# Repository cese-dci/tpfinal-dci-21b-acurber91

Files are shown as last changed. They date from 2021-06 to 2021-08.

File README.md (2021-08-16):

## Trabajo Práctico Final de la asignatura DCI ##

Este repositorio contiene el Trabajo Práctico Final de la asignatura de Diseño de Circuitos Impresos de la carrera Maestría en Internet de las Cosas (MIoT) de la FIUBA.

* **Autor**: Agustín Curcio Berardi
* **Revisor**: Gustavo Zocco
* **Docente**: Diego Brengui
* **Título del Trabajo**:  Adafruit Feather M0 with LoRa Radio Module Adaptation
* **Descripción**:  Plataforma modular Feather desarrollada por Adafruit con el mismo concepto de las placas Arduino. Existen diversas placas con un mismo formato físico y diferente hardware montado. Esta versión en particular incorpora un microcontrolador ARM Cortex-M0 junto con un módulo LoRa basado en el chipset SX1276 de la empresa Semtech.

<p align="center">
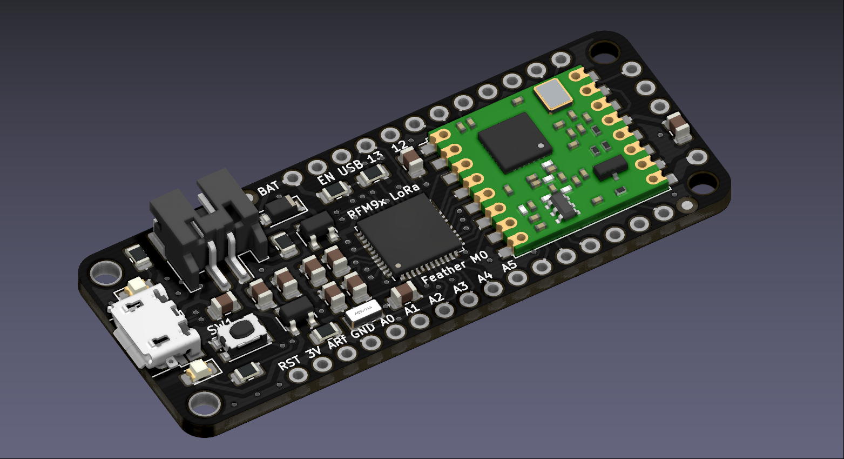
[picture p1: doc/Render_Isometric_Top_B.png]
    <br>
    <b>Figura 1</b>. Vista isométrica superior de la adaptación realizada. 
</p>

<p align="center">
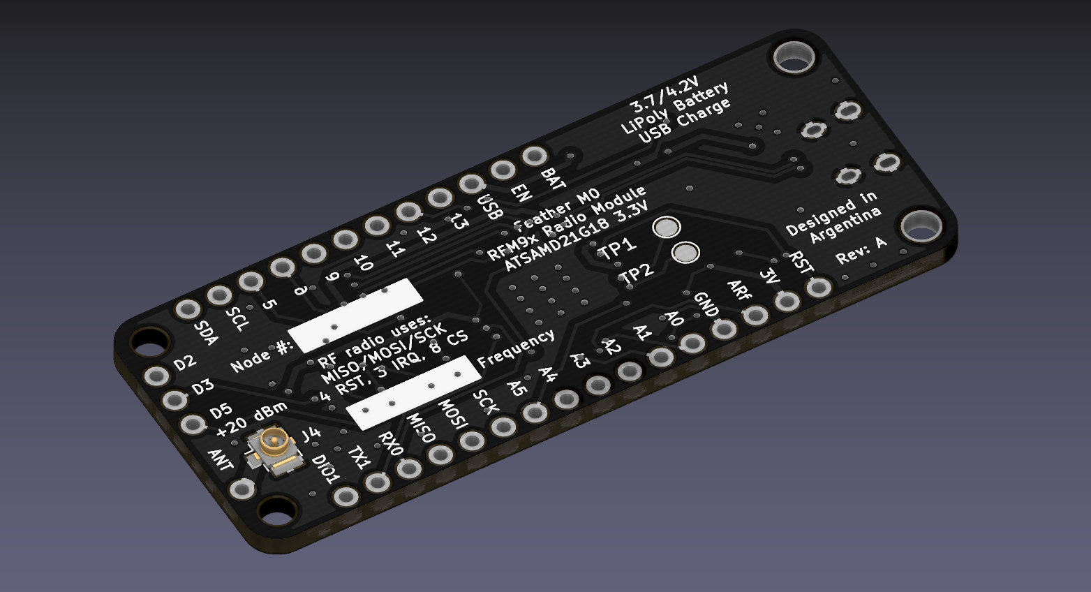
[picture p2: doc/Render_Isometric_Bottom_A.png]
    <br>
    <b>Figura 2</b>. Vista isométrica inferior de la adaptación realizada. 
</p>

<p align="center">
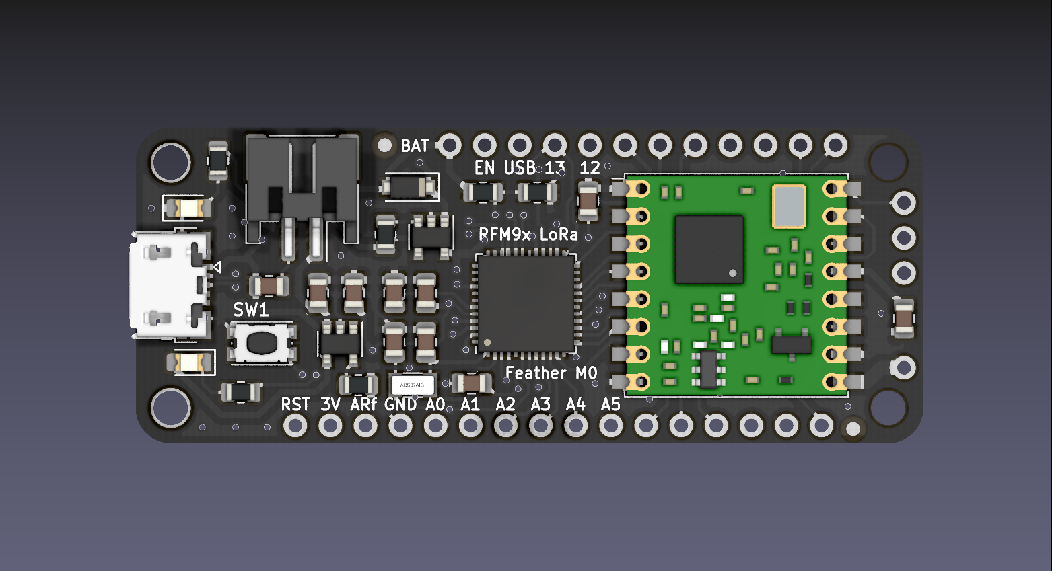
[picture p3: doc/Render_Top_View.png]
    <br>
    <b>Figura 3</b>. Vista superior de la adaptación realizada. 
</p>

<p align="center">
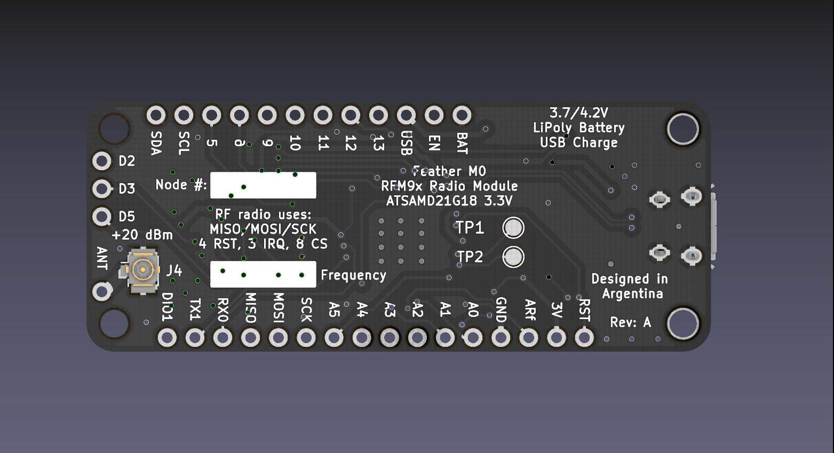
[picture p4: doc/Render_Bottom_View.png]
    <br>
    <b>Figura 4</b>. Vista inferior de la adaptación realizada. 
</p>

## Detalles de la adaptación ##

Este Trabajo Práctico realizó una adaptación de la placa utilizada como propuesta para poder cumplir con los requerimientos establecidos en la materia. Así:

- Se modificaron los tamaños de los componentes pasivos. Se pasó de tamaño 0603 a 0805.
- El cambio de tamaño de los componentes pasivos requirió modificar las dimensiones del circuito impreso. La altura no se modificó para garantizar la compatibilidad con otras placas de la línea Feather. No obstante, sí se modificó el largo total de la misma para hacer lugar a componentes de mayor tamaño. El circuito impreso final es 6,223 mm más largo que el original.
- Se agregó un segundo fiducial que no estaba presente en el diseño original.
- Se adoptó HASL como terminación superficial en lugar de ENIG.

## Licencia de este trabajo ##
Designed by Limor Fried/Ladyada for Adafruit Industries. Creative Commons Attribution/Share-Alike. See License.txt for additional information.

## Estructura ##

El Trabajo Práctico Final tiene la siguiente estructura:

* doc: Toda la información sobre el circuito, principalmente de autoría o procesamiento propio.
  * Notas con cálculos.
  * Fotos de los prototipos.
* info: Toda la información recolectada, principalmente de terceros, como por ejemplo:
  * Hojas de datos.
  * Notas de aplicación.
  * Información de productos comerciales.
* pcb: Archivos de diseño esquemático y PCB.
  * Archivo esquemático en PDF.

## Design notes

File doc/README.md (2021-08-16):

## Cálculos ##

Si bien no se encontraba dentro del alcance del Trabajo Práctico calcular líneas de impedancia controlada, se efectuaron dichos cálculos utilizando la calculadora de KiCad y los resultados obtenidos fueron aplicados en el circuito impreso. Se requirió calcular una línea diferencial para la conexión USB y una línea de transmisión para la conexión de antena. Los resultados de dichos cálculos se muestran en las Figuras 1 y 2.

<p align="center">
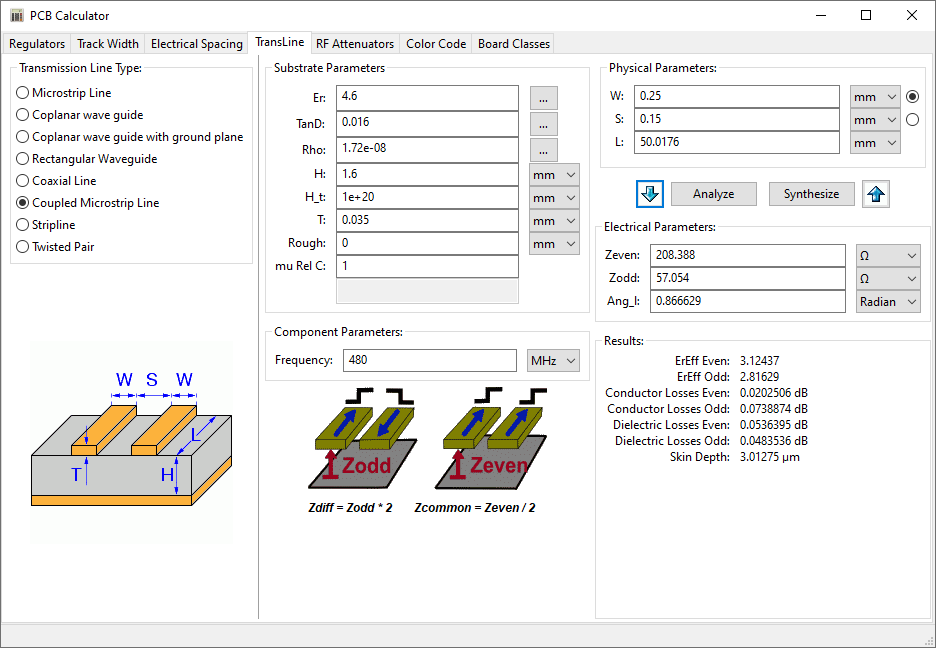
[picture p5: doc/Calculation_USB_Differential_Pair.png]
    <br>
    <b>Figura 1</b>. Cálculo de línea diferencial USB. 
</p>

<p align="center">
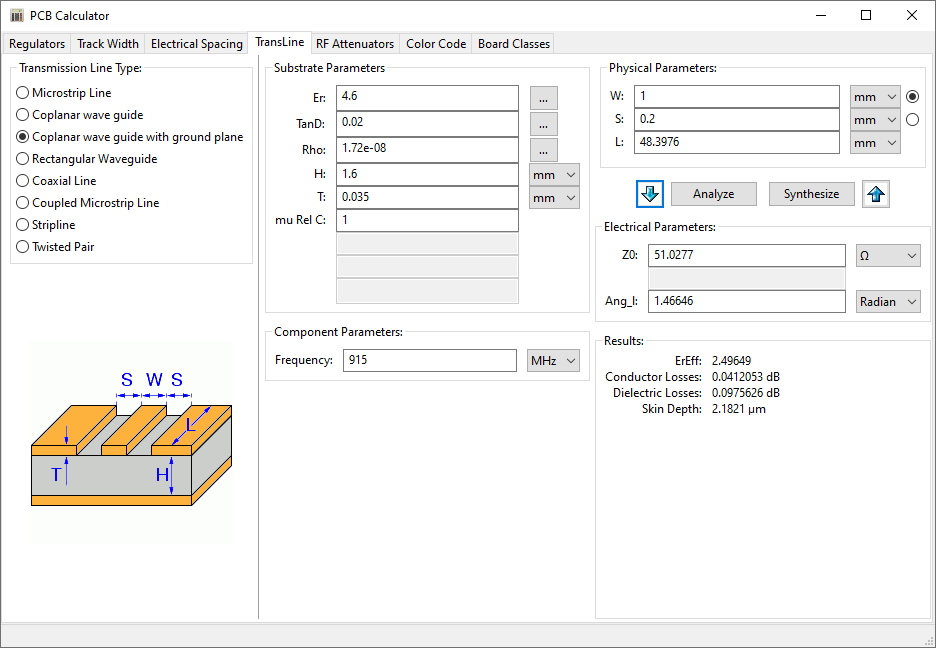
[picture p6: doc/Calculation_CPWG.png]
    <br>
    <b>Figura 2</b>. Cálculo de la línea de transmisión. 
</p>

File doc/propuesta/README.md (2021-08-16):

## Propuesta ##

Se propuso realizar una adaptación de la placa Adafruit Feather M0 Radio with LoRa Radio Module.

> <b>NOTA:</b> Más información sobre el trabajo se puede encontrar en las páginas web donde [se encuentra a la venta](https://www.adafruit.com/product/3178) junto con [los datos detallada de la misma](https://learn.adafruit.com/adafruit-feather-m0-radio-with-lora-radio-module/downloads).

<p align="center">
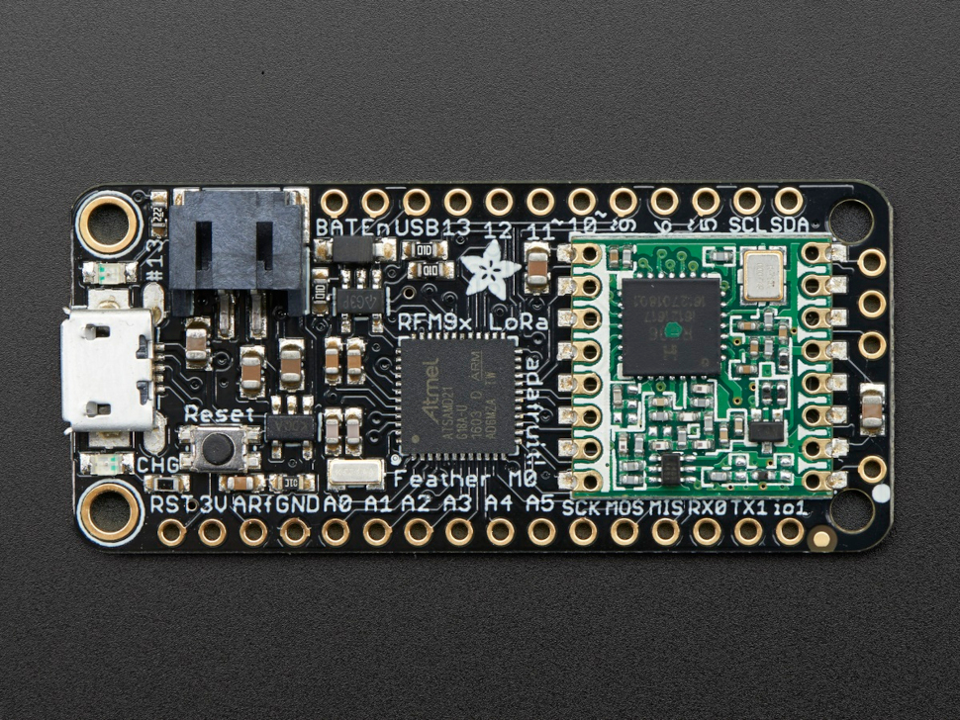
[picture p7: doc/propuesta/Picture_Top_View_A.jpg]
    <br>
    <b>Figura 1</b>. Vista superior de la placa. 
</p>

<p align="center">
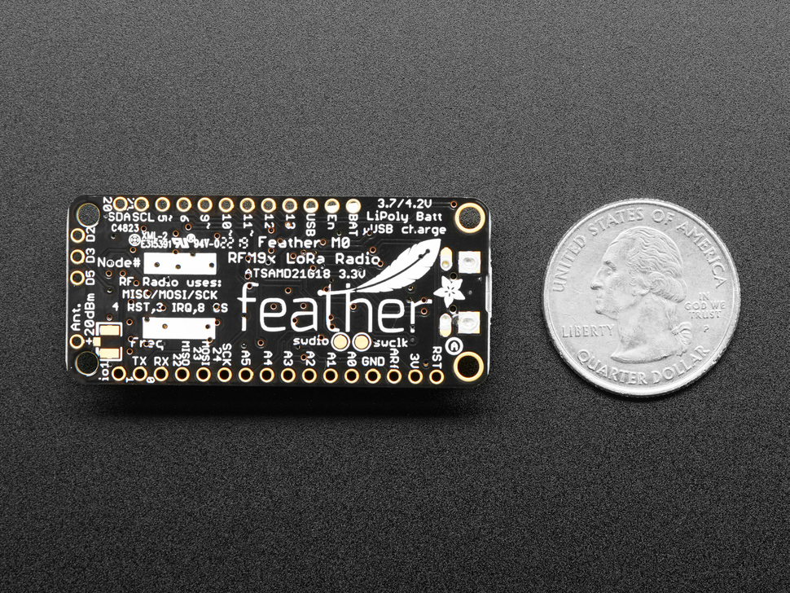
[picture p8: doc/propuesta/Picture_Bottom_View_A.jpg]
    <br>
    <b>Figura 2</b>. Vista inferior de la placa. 
</p>

<p align="center">
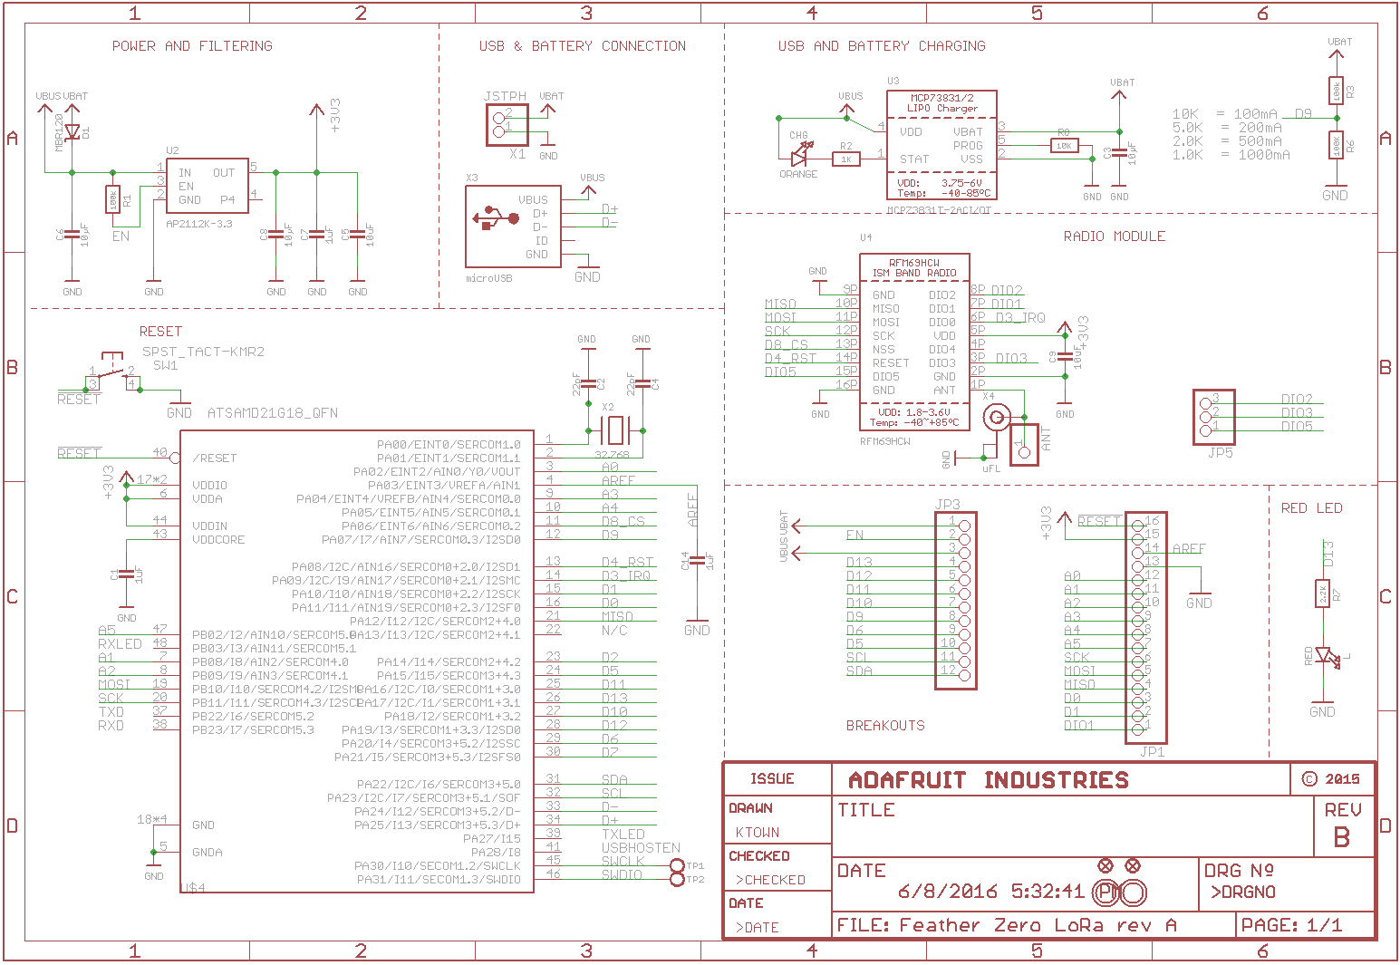
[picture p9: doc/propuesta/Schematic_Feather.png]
    <br>
    <b>Figura 3</b>. Diagrama esquemático. 
</p>

<p align="center">
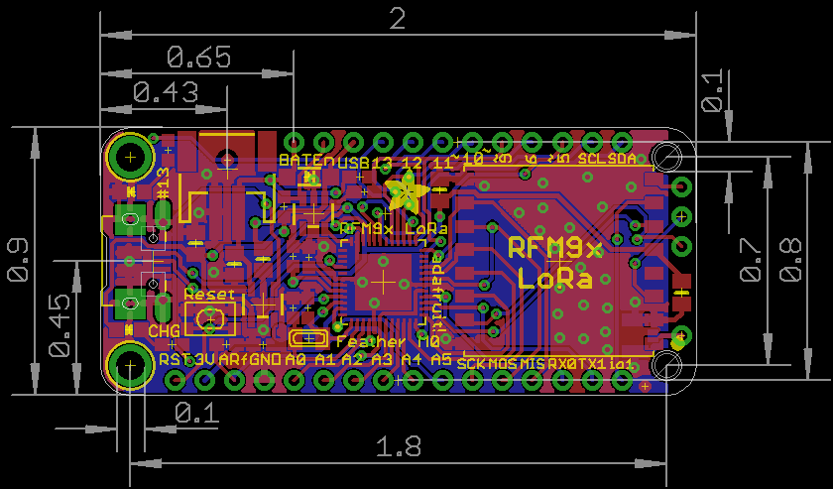
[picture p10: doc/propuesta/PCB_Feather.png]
    <br>
    <b>Figura 4</b>. Circuito impreso. 
</p>

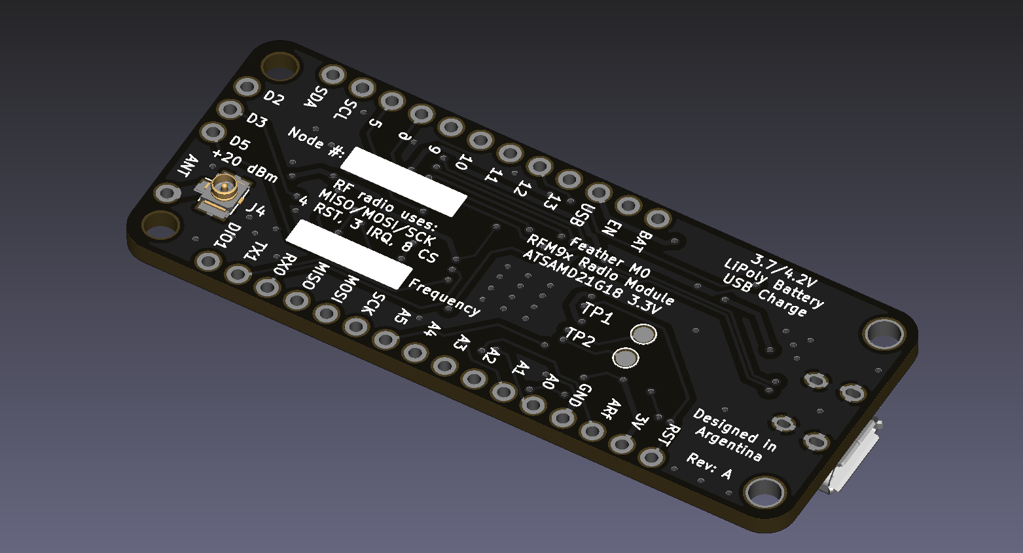
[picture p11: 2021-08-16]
doc/Render_Isometric_Bottom_B.png

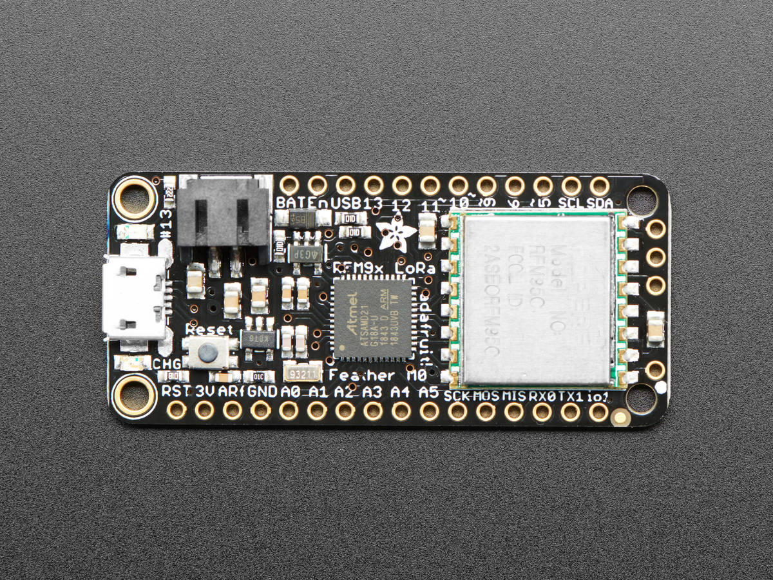
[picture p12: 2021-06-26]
doc/propuesta/Picture_Top_View_B.jpg

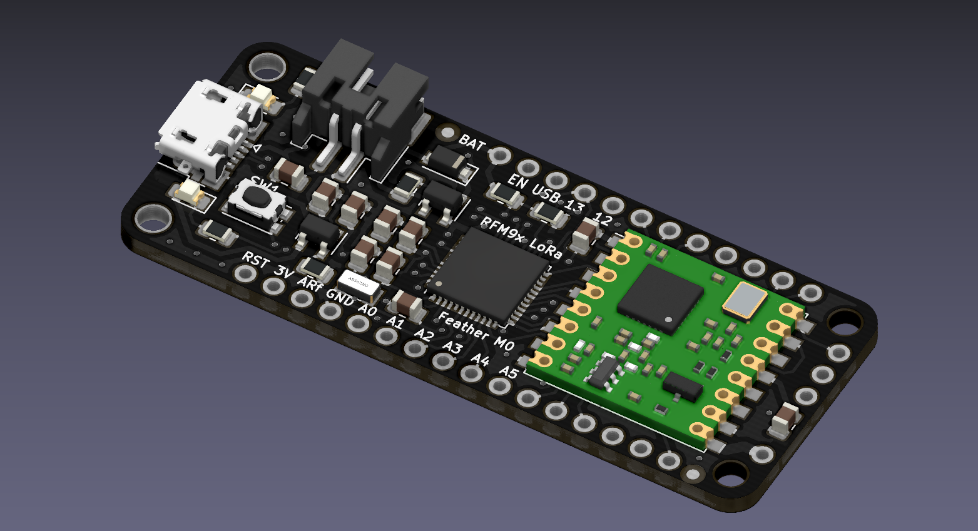
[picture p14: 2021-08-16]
doc/Render_Isometric_Top_A.png

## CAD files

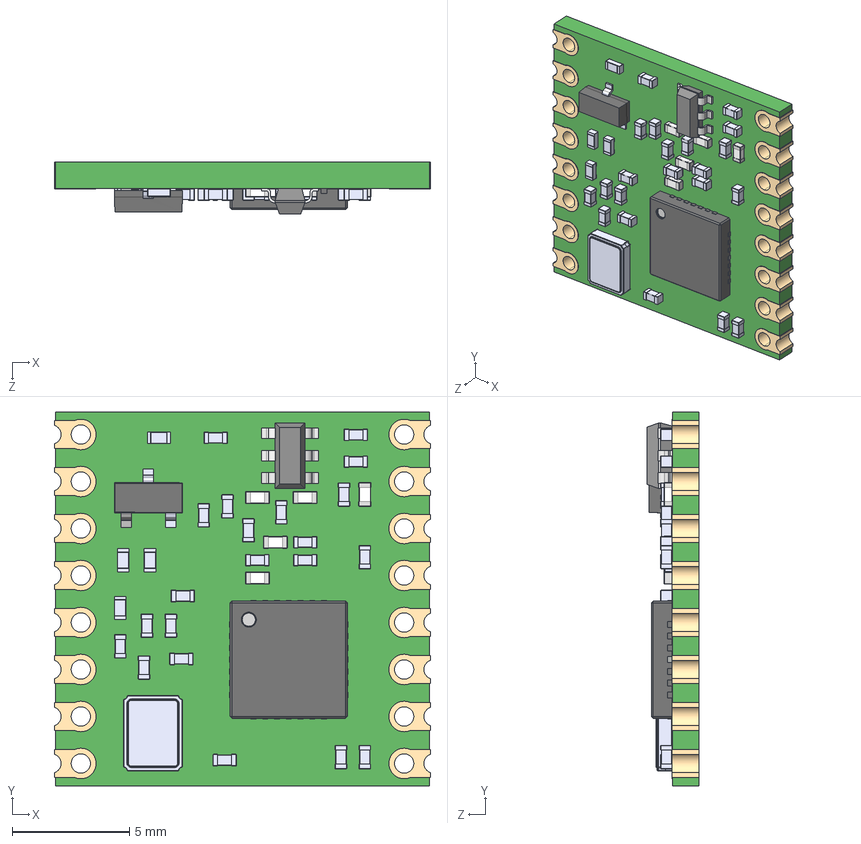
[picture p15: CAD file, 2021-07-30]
pcb/3d_models/Hoperf_RFM_95_96_97_98_1.step
16.0 x 15.9 x 2.23 mm
Board
Cap0402 x 21
SW3dPS-inductor_0402_white x 5
SW3dPS-SOT-23-6
QFN28
TXC_7M
Res0402 x 4
User_Library-3-lead_sot23-3
Goldcontact x 16

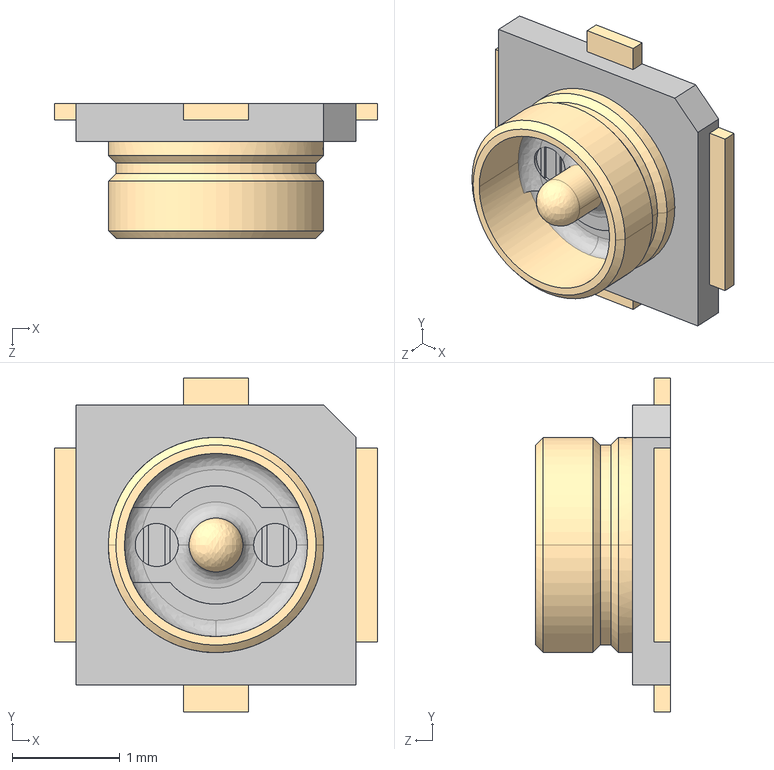
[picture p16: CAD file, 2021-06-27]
pcb/3d_models/Hirose_U.FL.step
3.00 x 3.10 x 1.25 mm

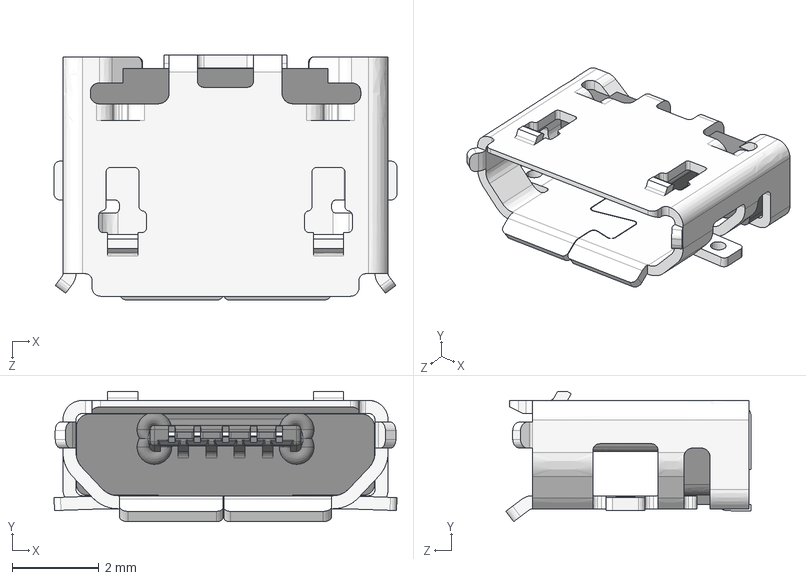
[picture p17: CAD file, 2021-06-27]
pcb/3d_models/Amphenol_10118192C.step
7.91 x 3.01 x 5.66 mm

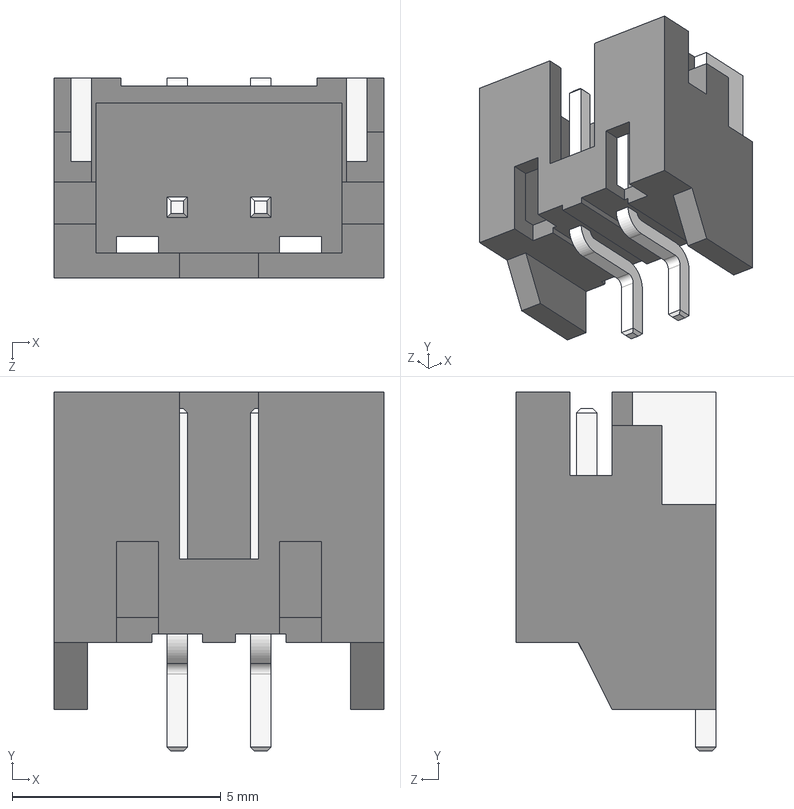
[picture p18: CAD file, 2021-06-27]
pcb/3d_models/JST_Connector.step
7.90 x 8.60 x 4.80 mm

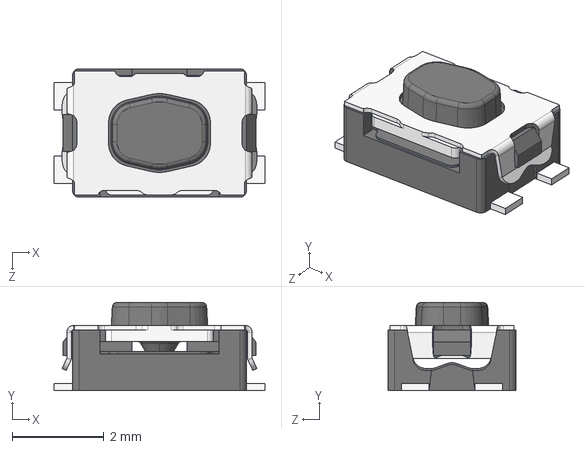
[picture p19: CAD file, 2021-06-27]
pcb/3d_models/C&K_KMR2_Switch.step
4.60 x 1.92 x 2.80 mm

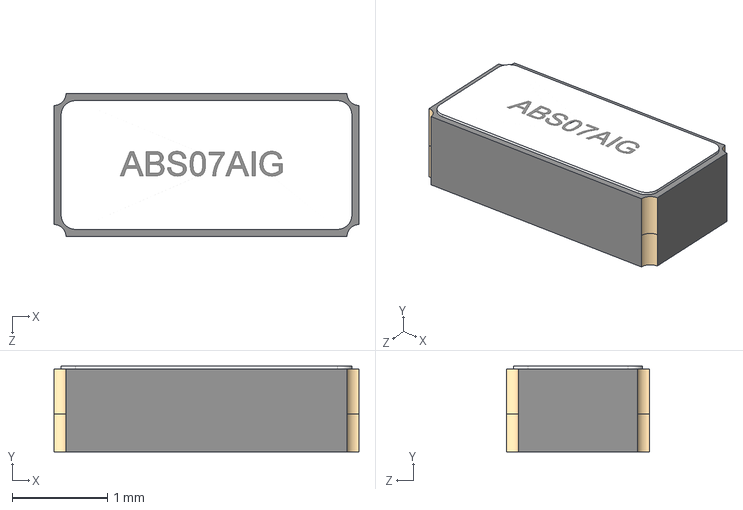
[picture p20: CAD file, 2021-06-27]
pcb/3d_models/Abracon_ABS07AIG.step
3.20 x 0.901 x 1.50 mm

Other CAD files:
pcb/3d_models/Hoperf_RFM_95_96_97_98.step

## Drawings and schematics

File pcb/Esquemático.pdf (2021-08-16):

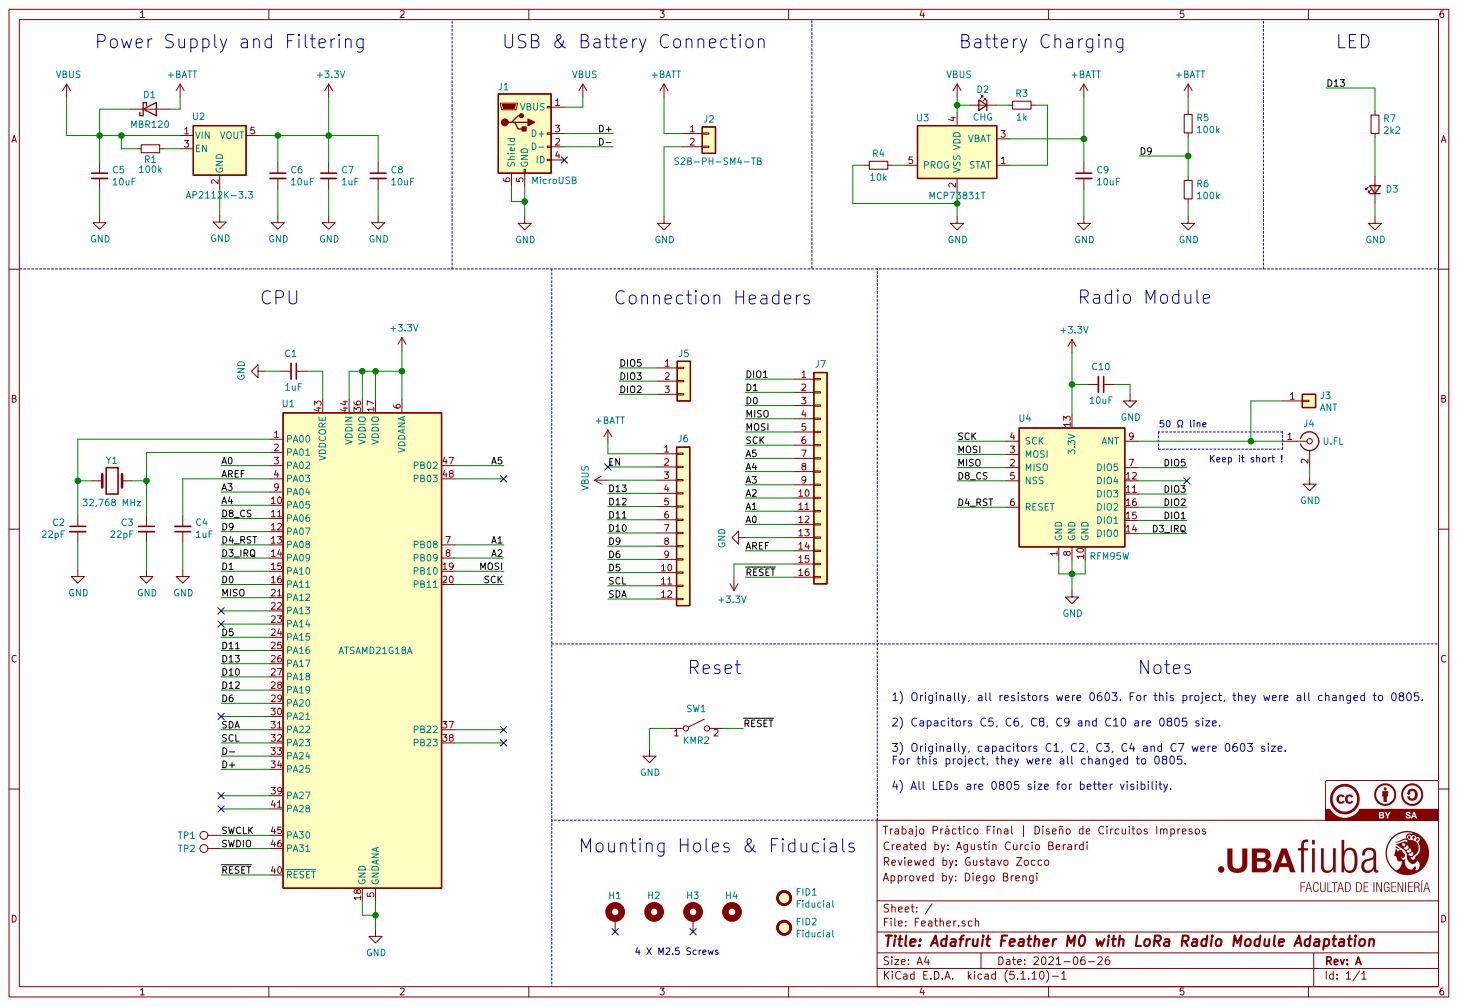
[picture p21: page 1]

Power Supply and Filtering

1 GND 10 DIO3 11 DIO4 12 3.3V 13 DIO0 14 DIO1 15 DIO2 16 MISO 2 MOSI 3 SCK 4 NSS 5 RESET 6 DIO5 7 GND

1) Originally, all resistors were 0603. For this project, they were all changed to 0805.

2) Capacitors C5, C6, C8, C9 and C10 are 0805 size.

3) Originally, capacitors C1, C2, C3, C4 and C7 were 0603 size.
For this project, they were all changed to 0805.

4) All LEDs are 0805 size for better visibility.

Created by: Agustín Curcio Berardi
Reviewed by: Gustavo Zocco
File: Feather.sch Sheet: / Approved by: Diego Brengi

Id: 1/1 Title: Adafruit Feather M0 with LoRa Radio Module Adaptation

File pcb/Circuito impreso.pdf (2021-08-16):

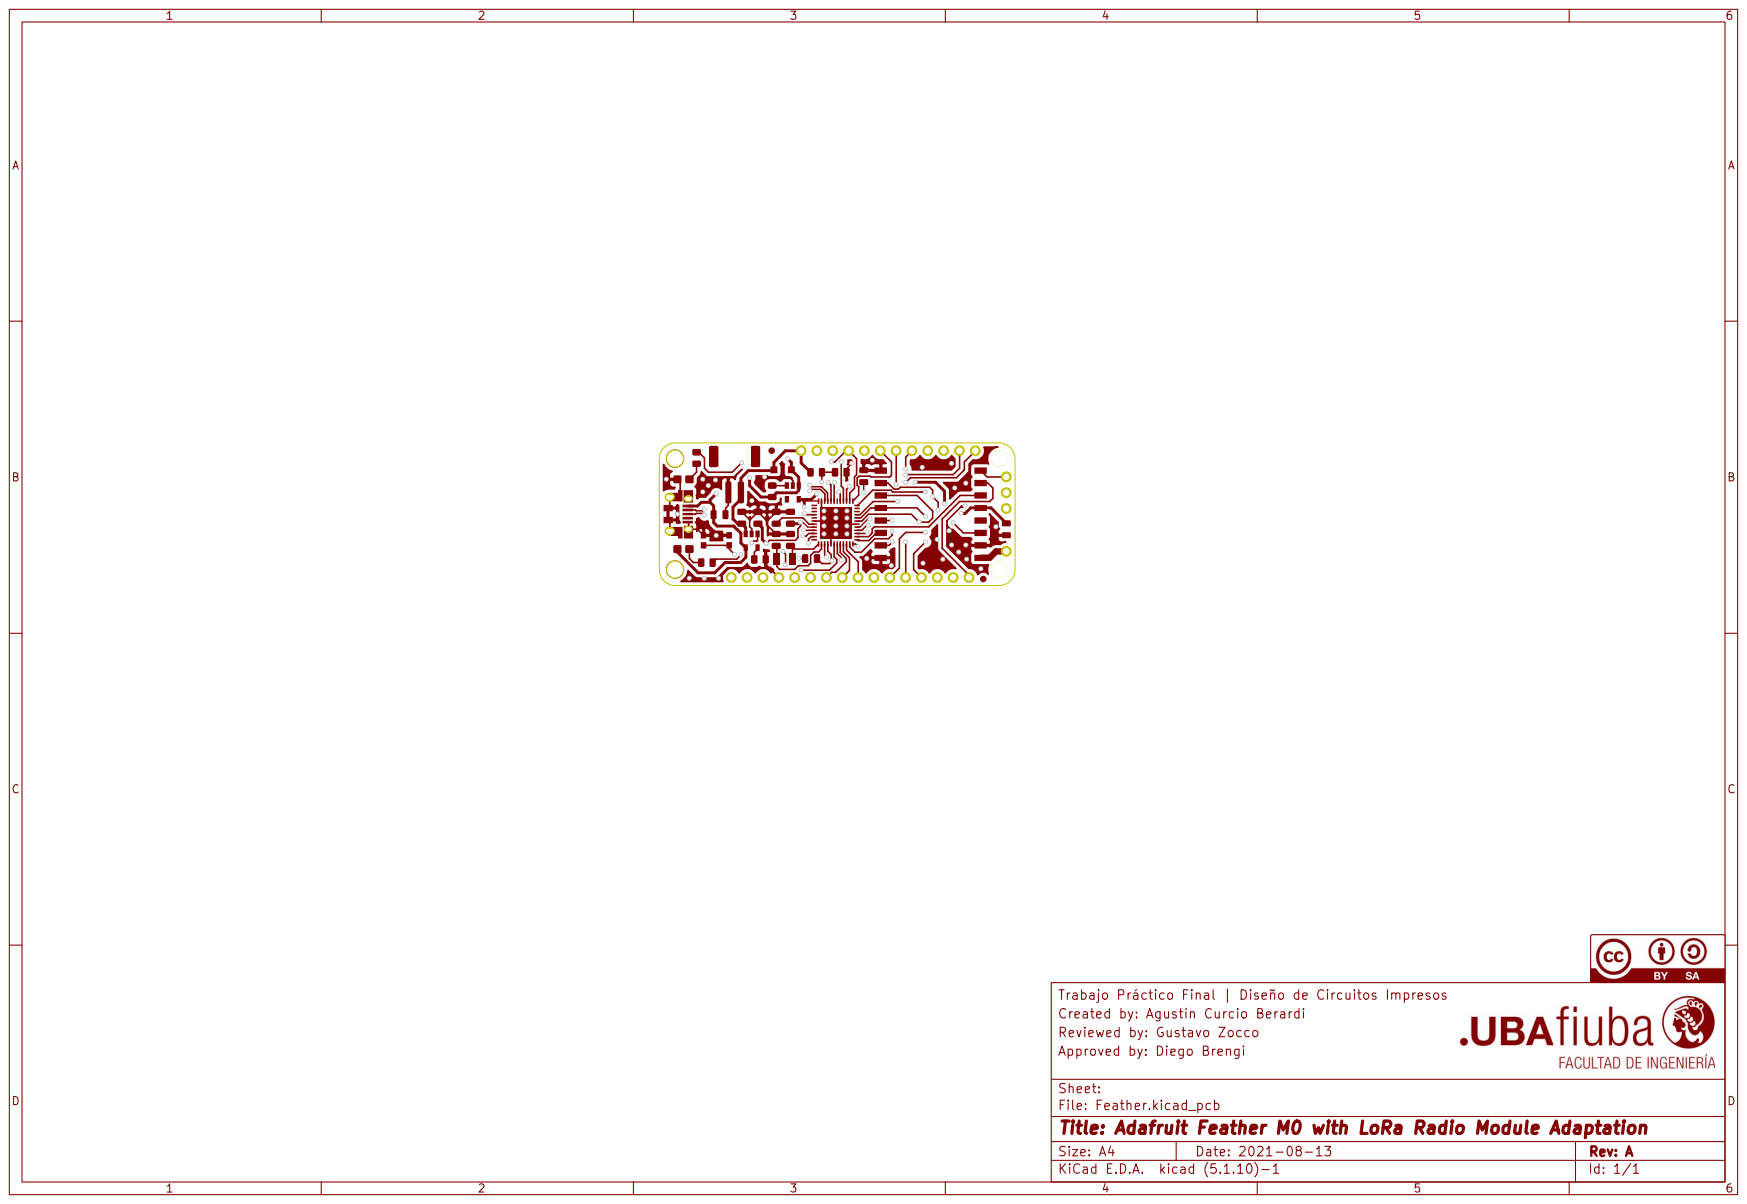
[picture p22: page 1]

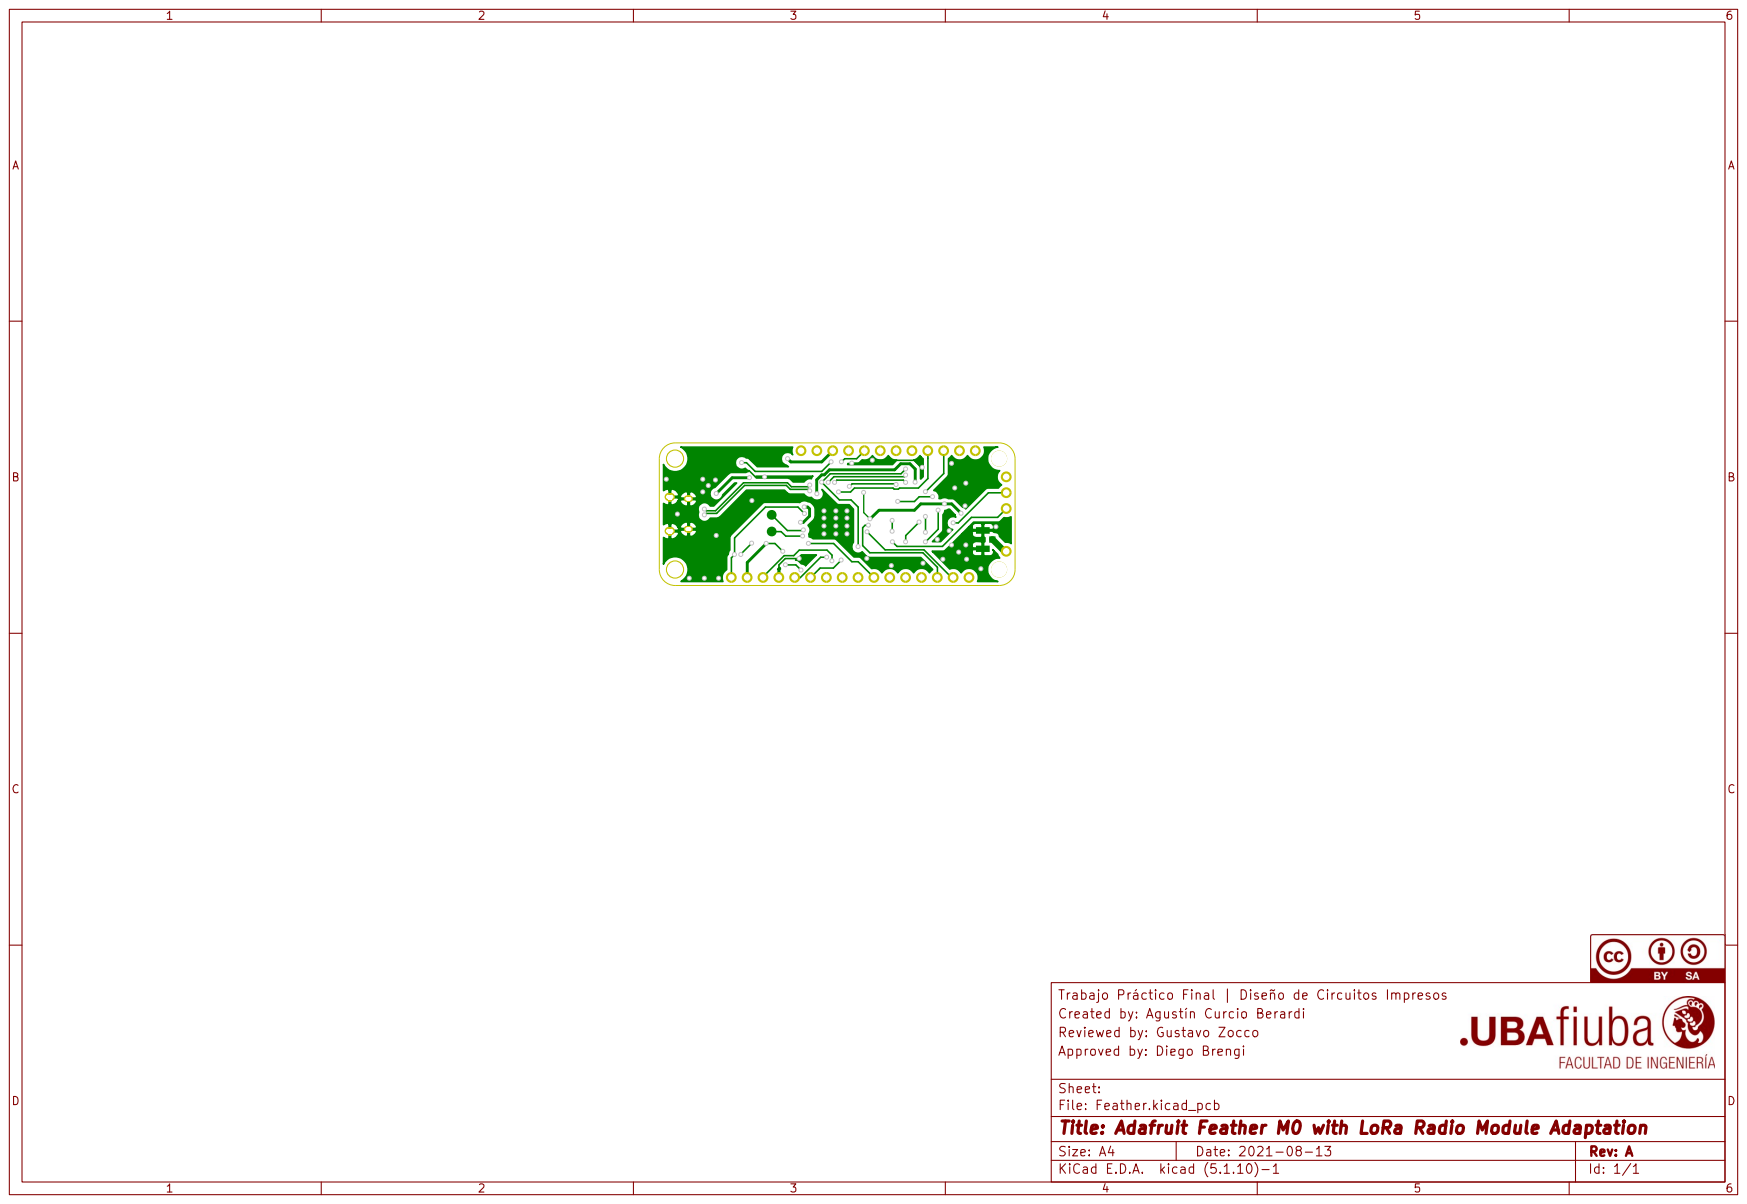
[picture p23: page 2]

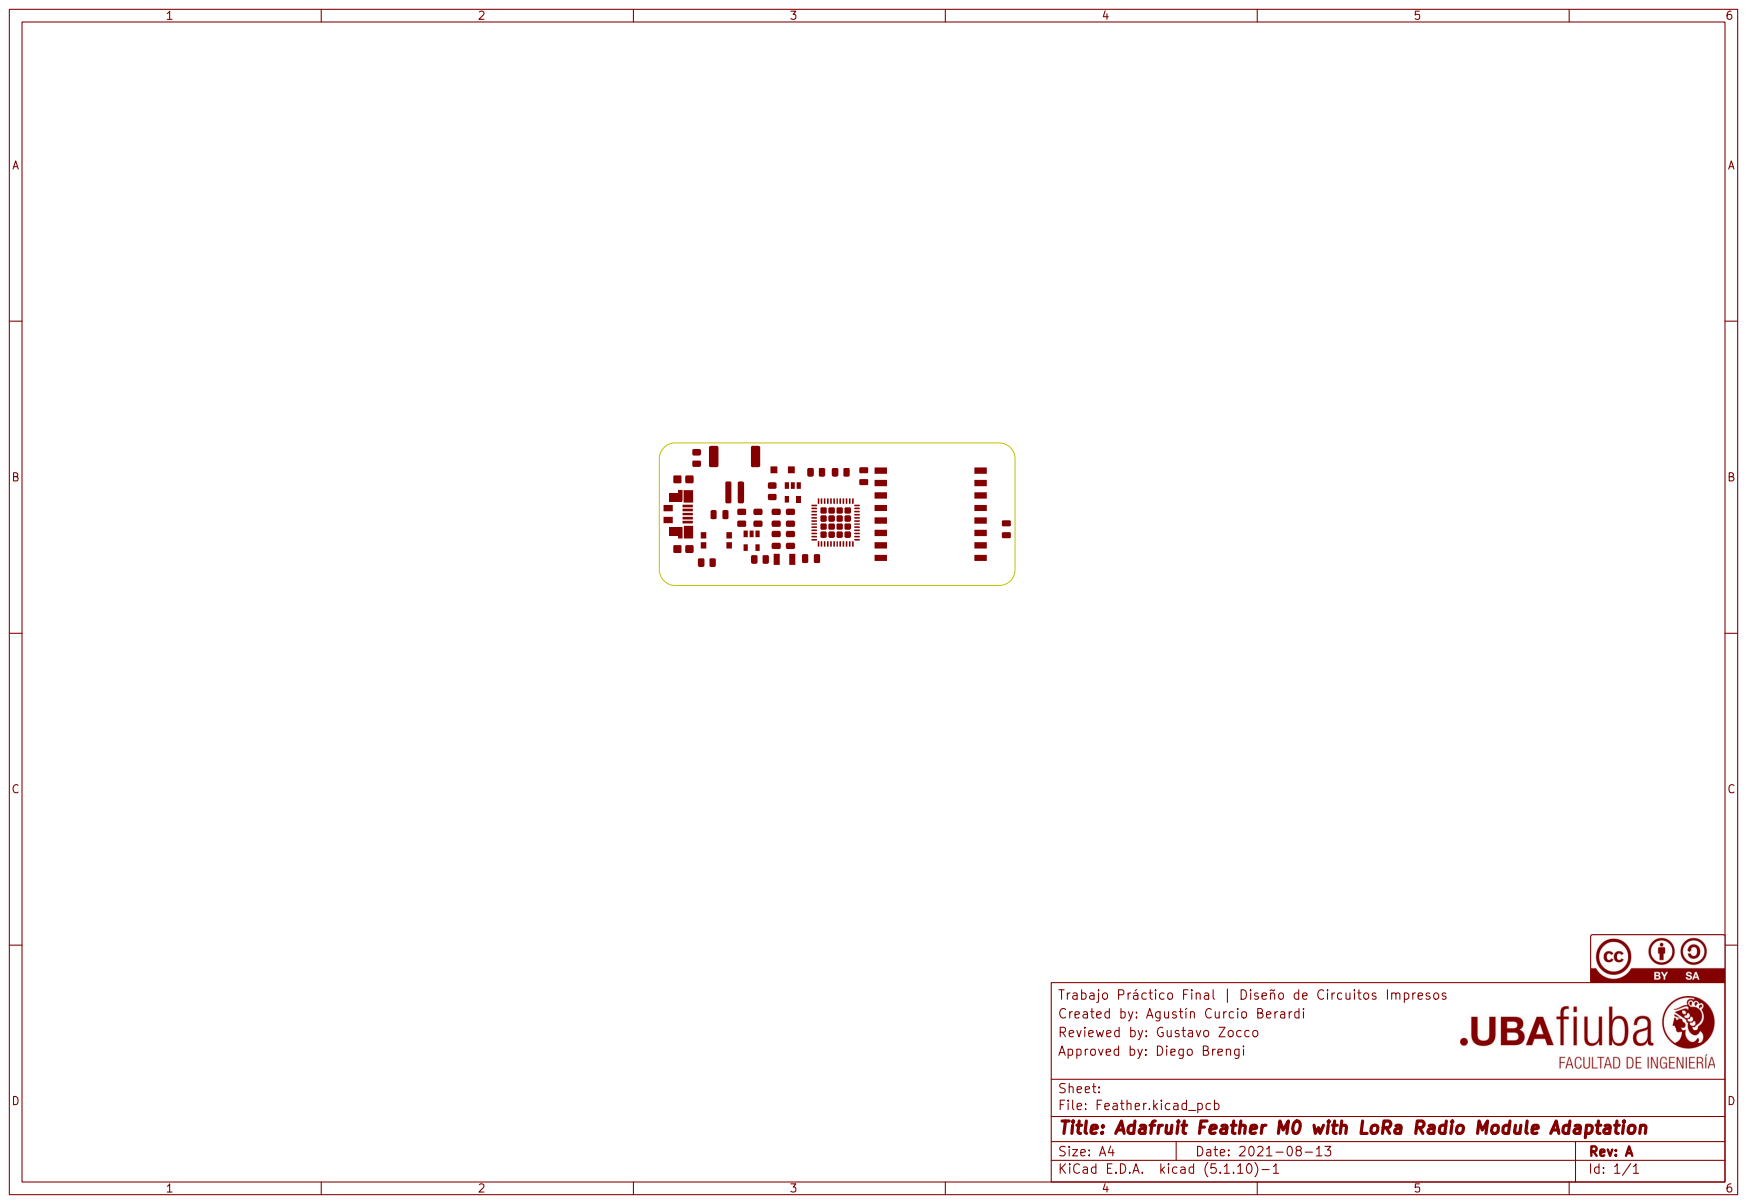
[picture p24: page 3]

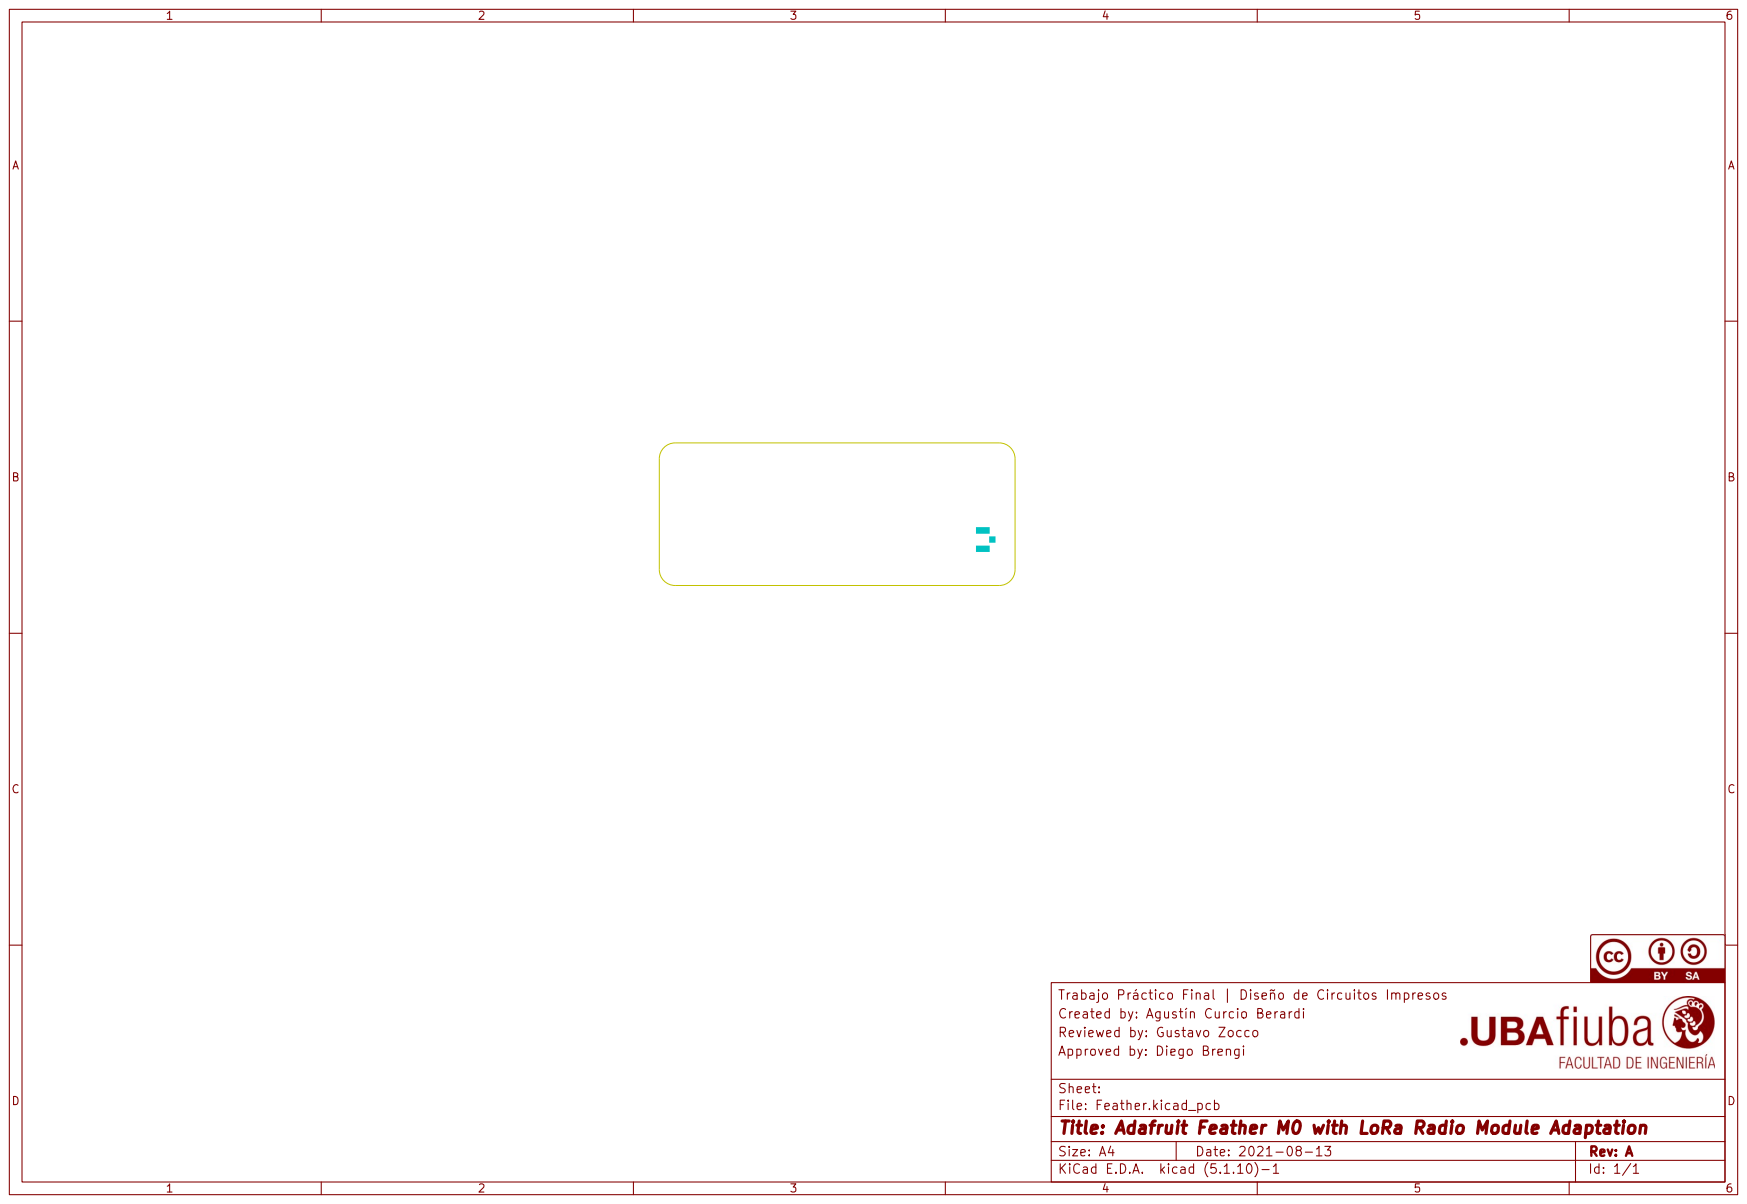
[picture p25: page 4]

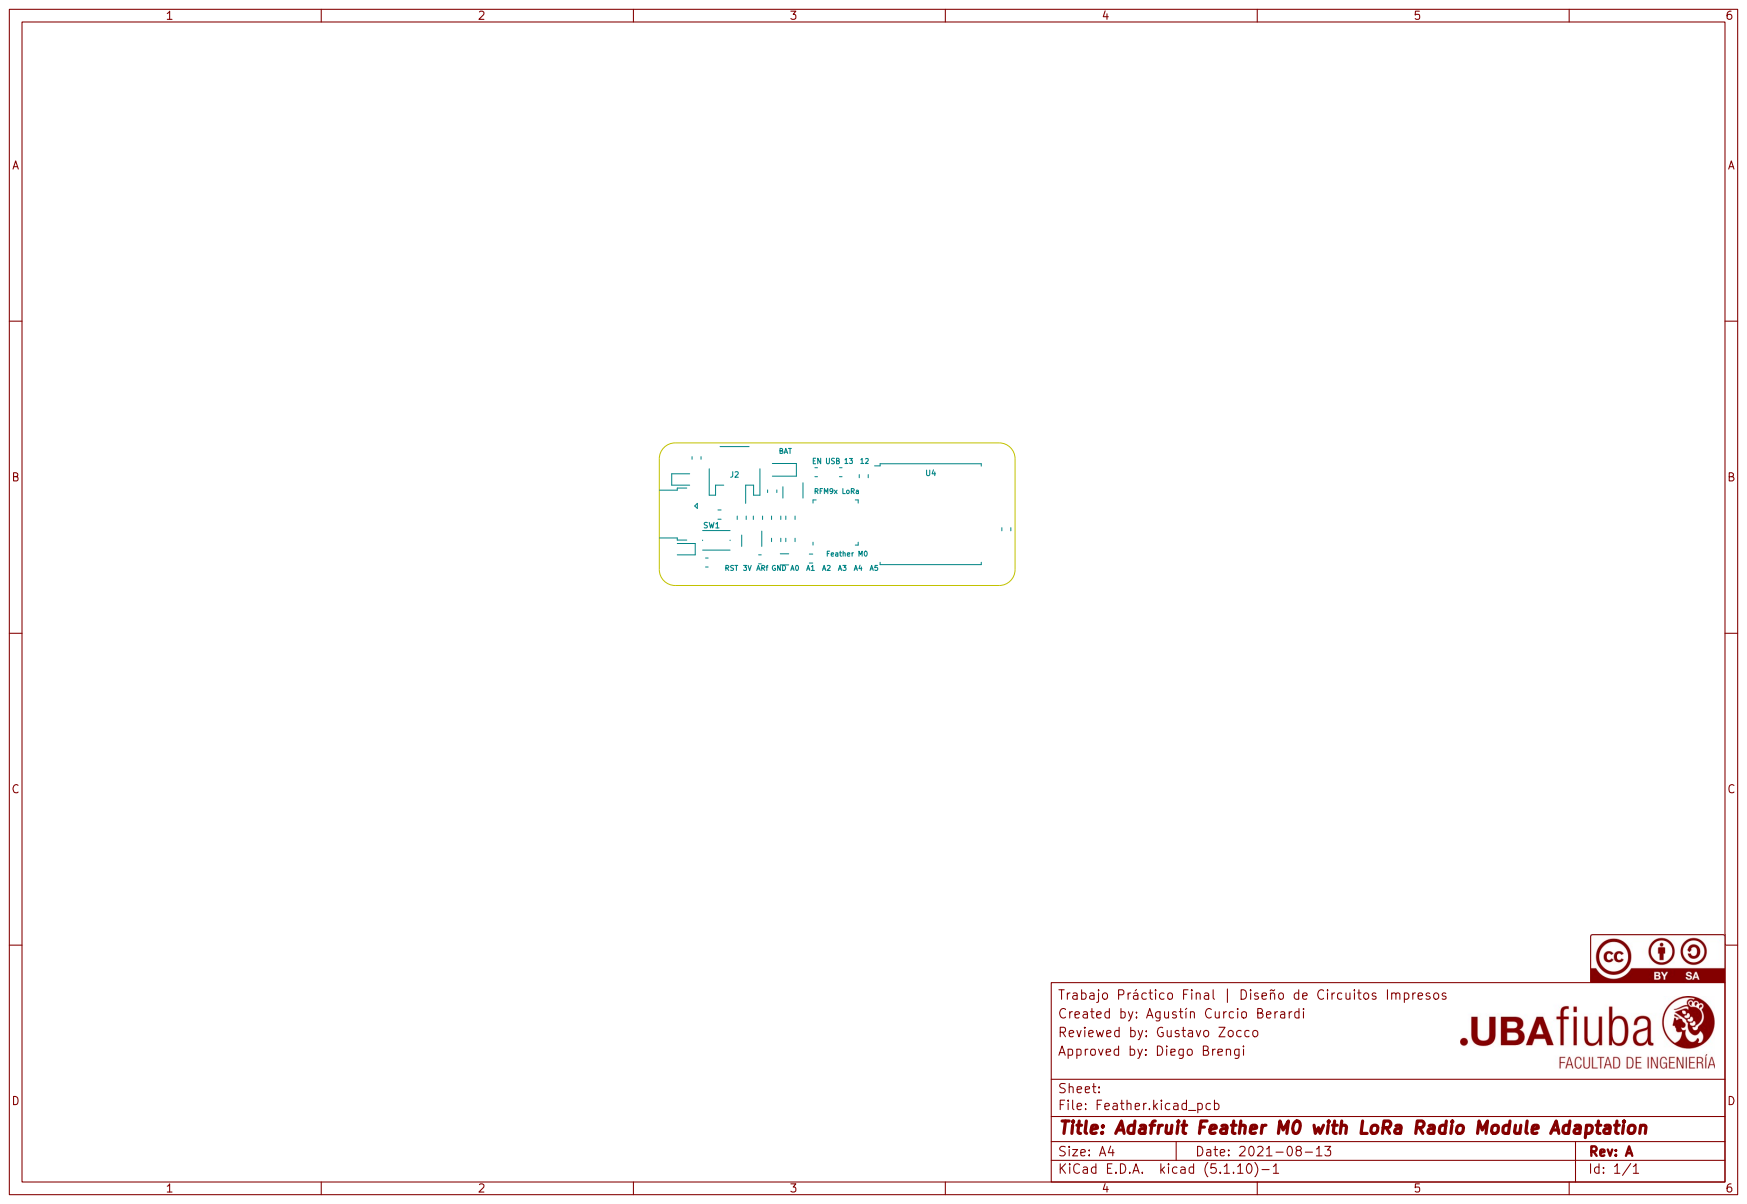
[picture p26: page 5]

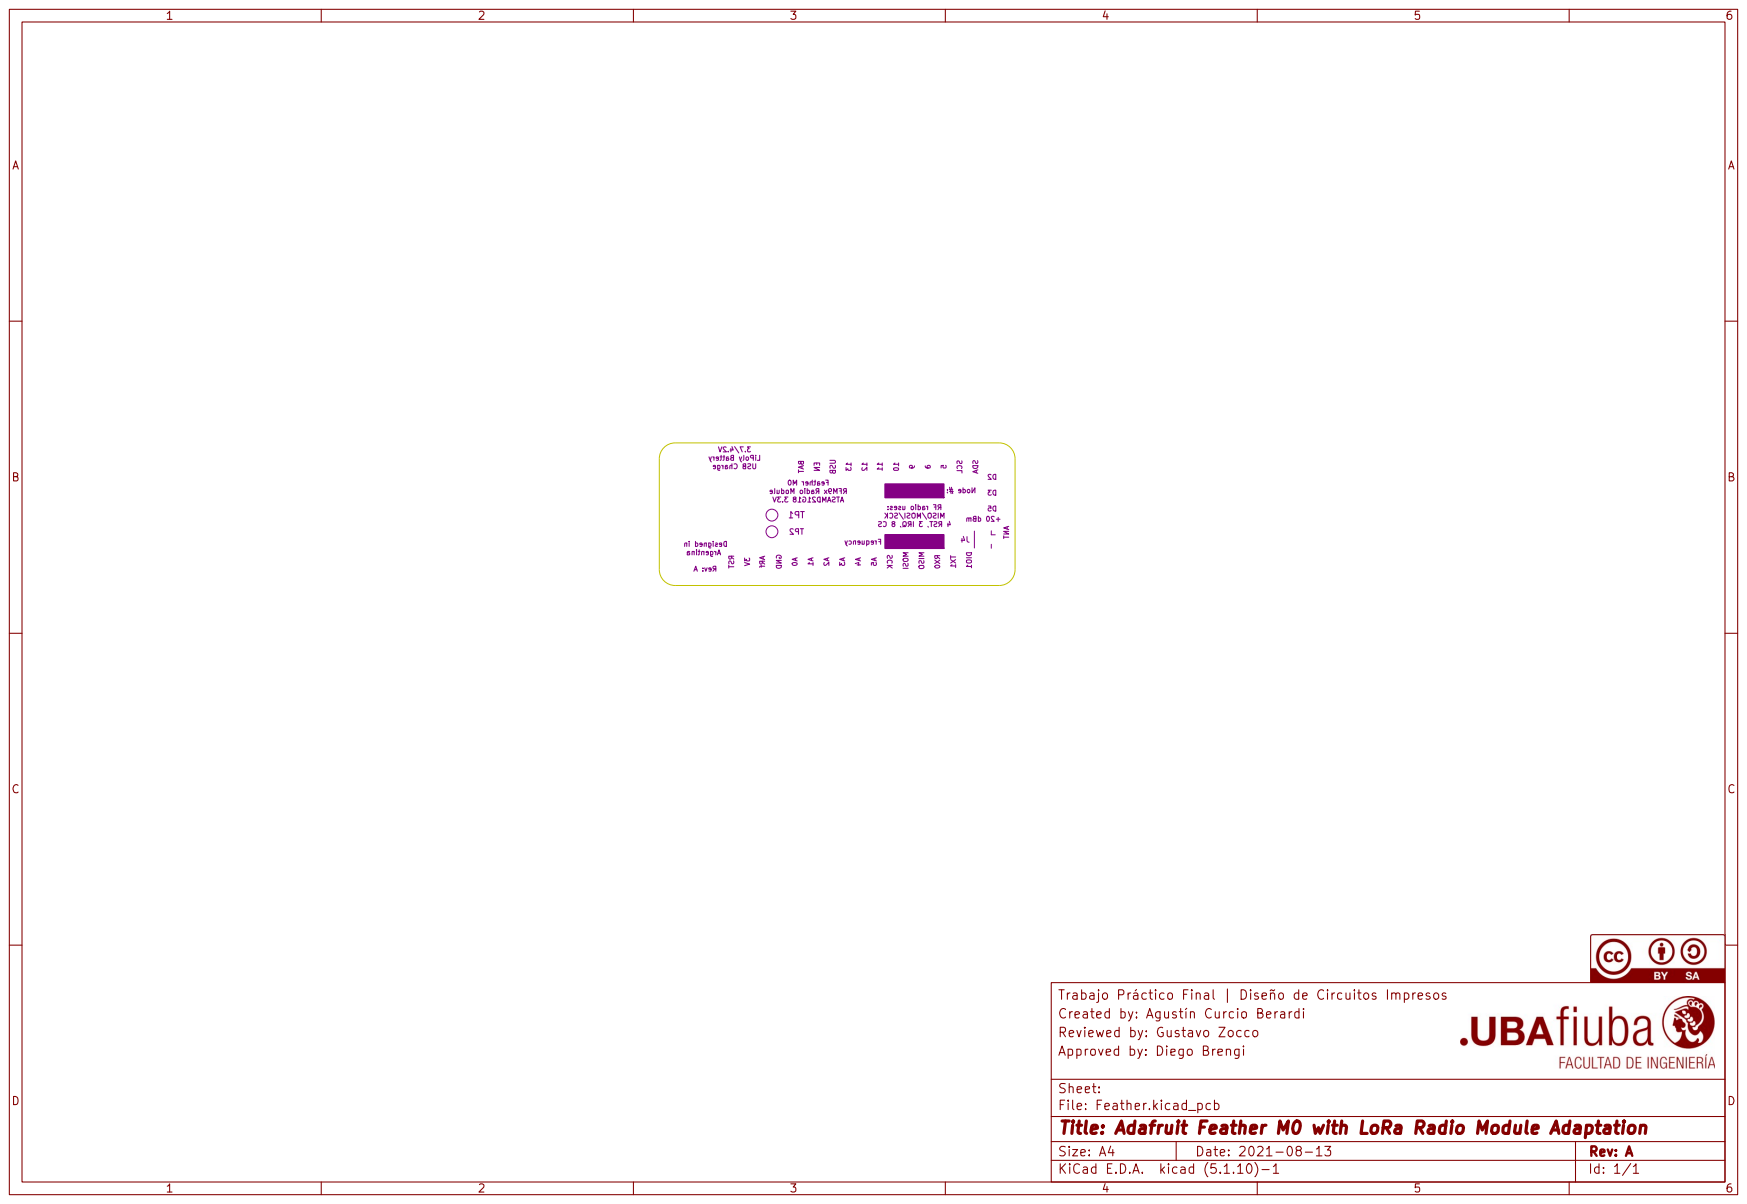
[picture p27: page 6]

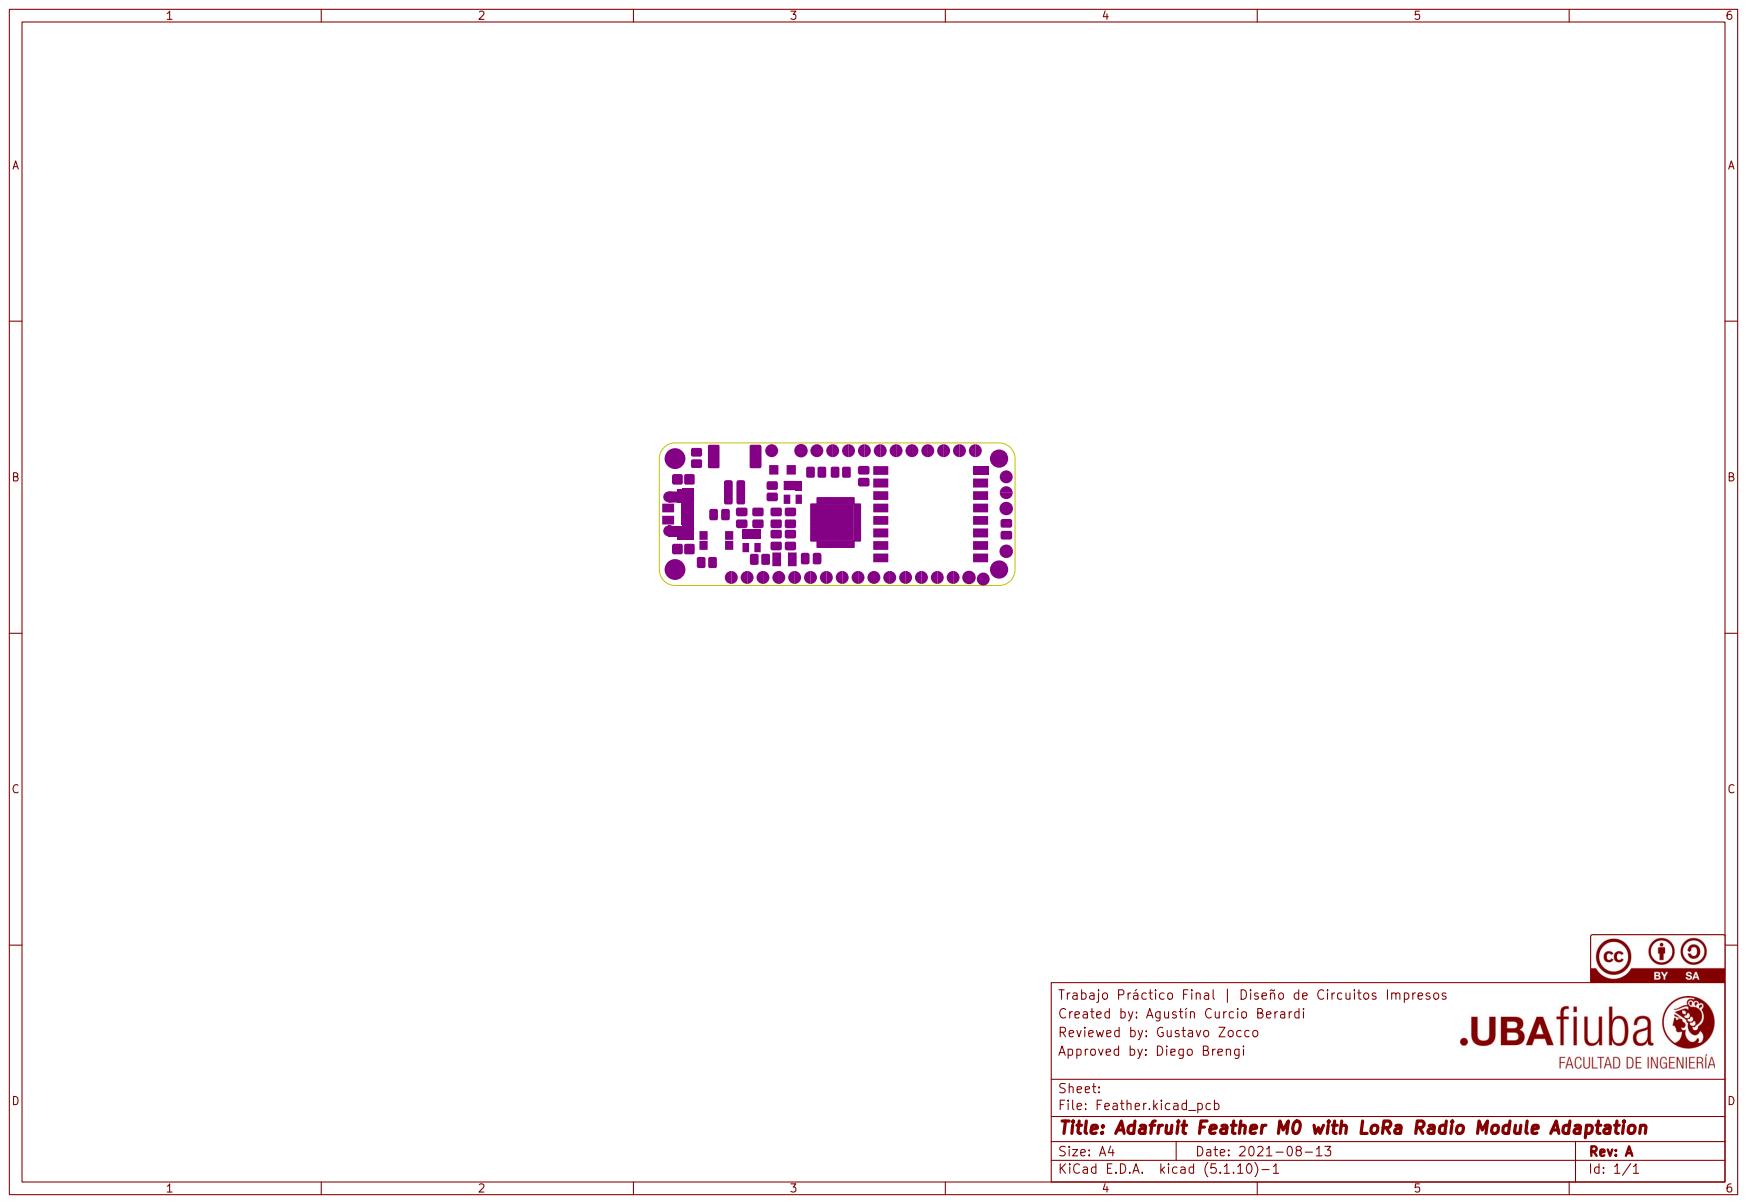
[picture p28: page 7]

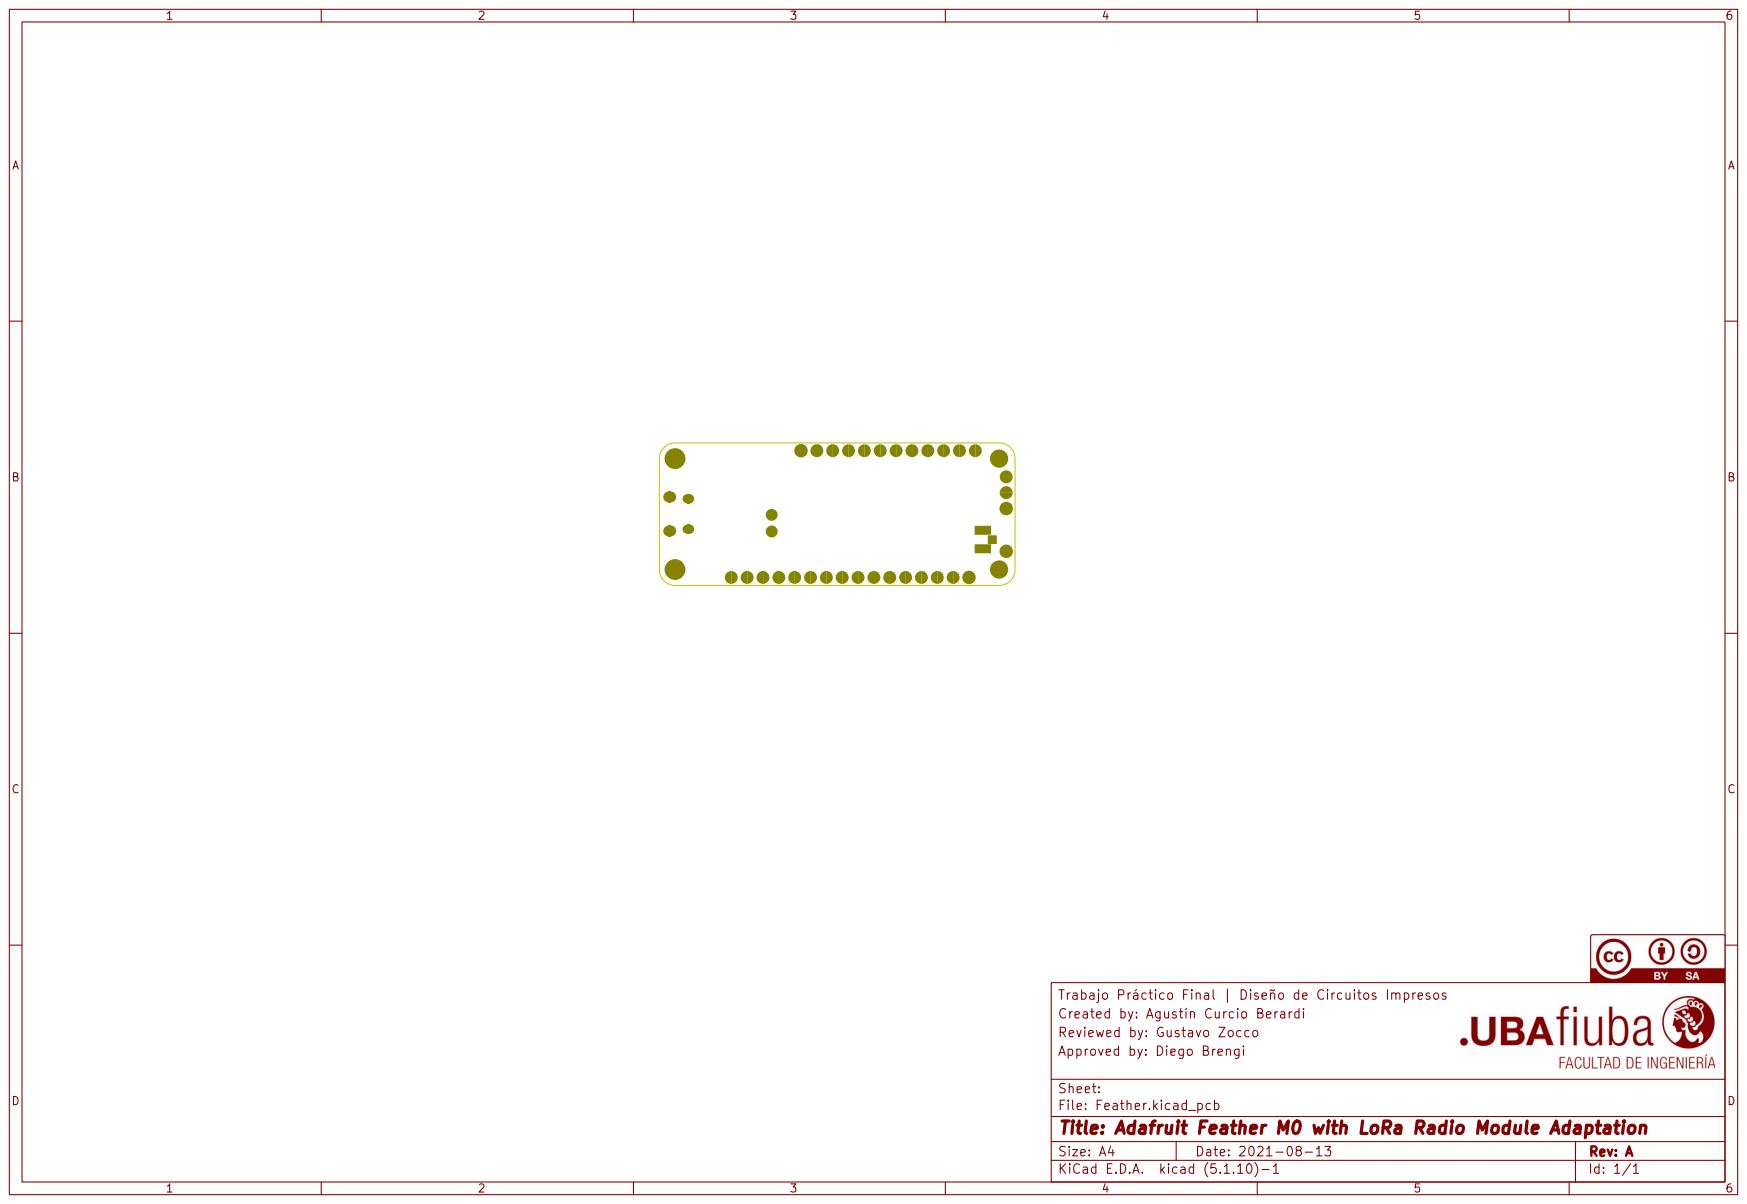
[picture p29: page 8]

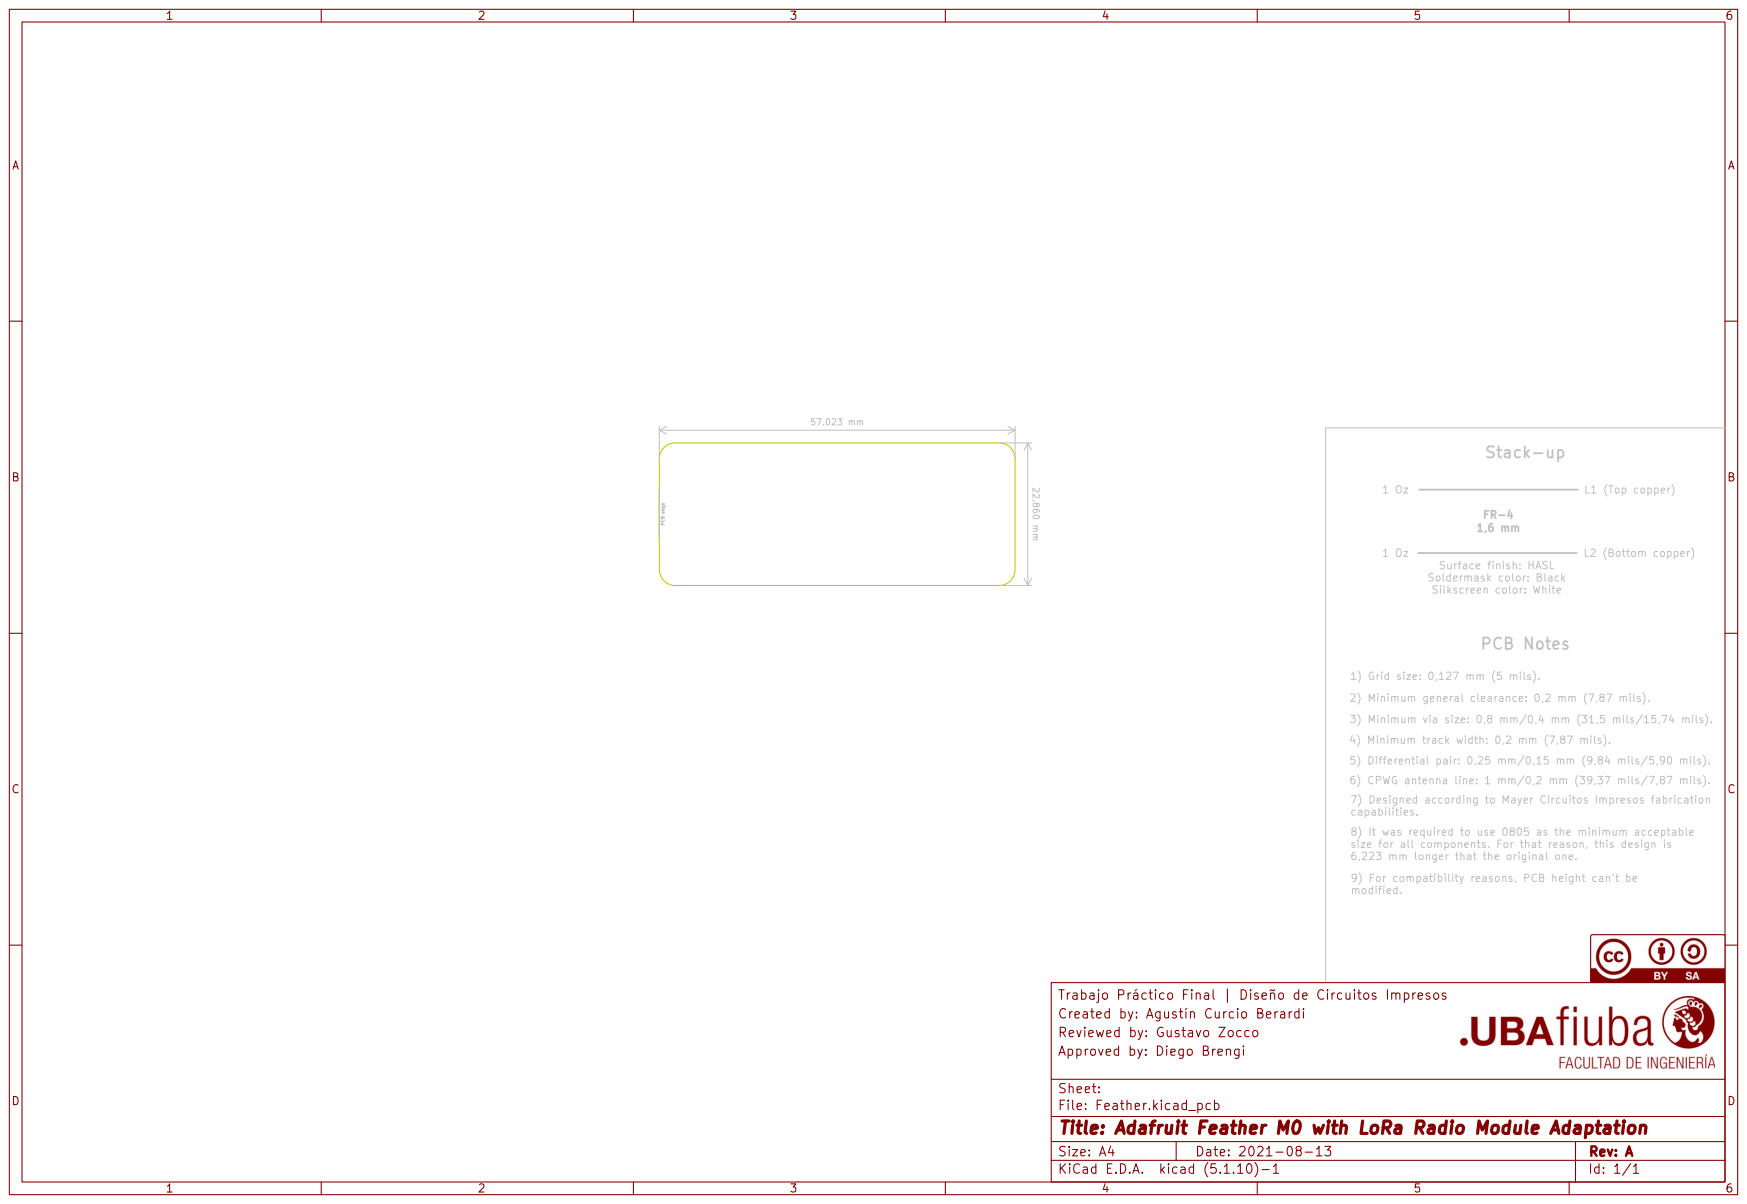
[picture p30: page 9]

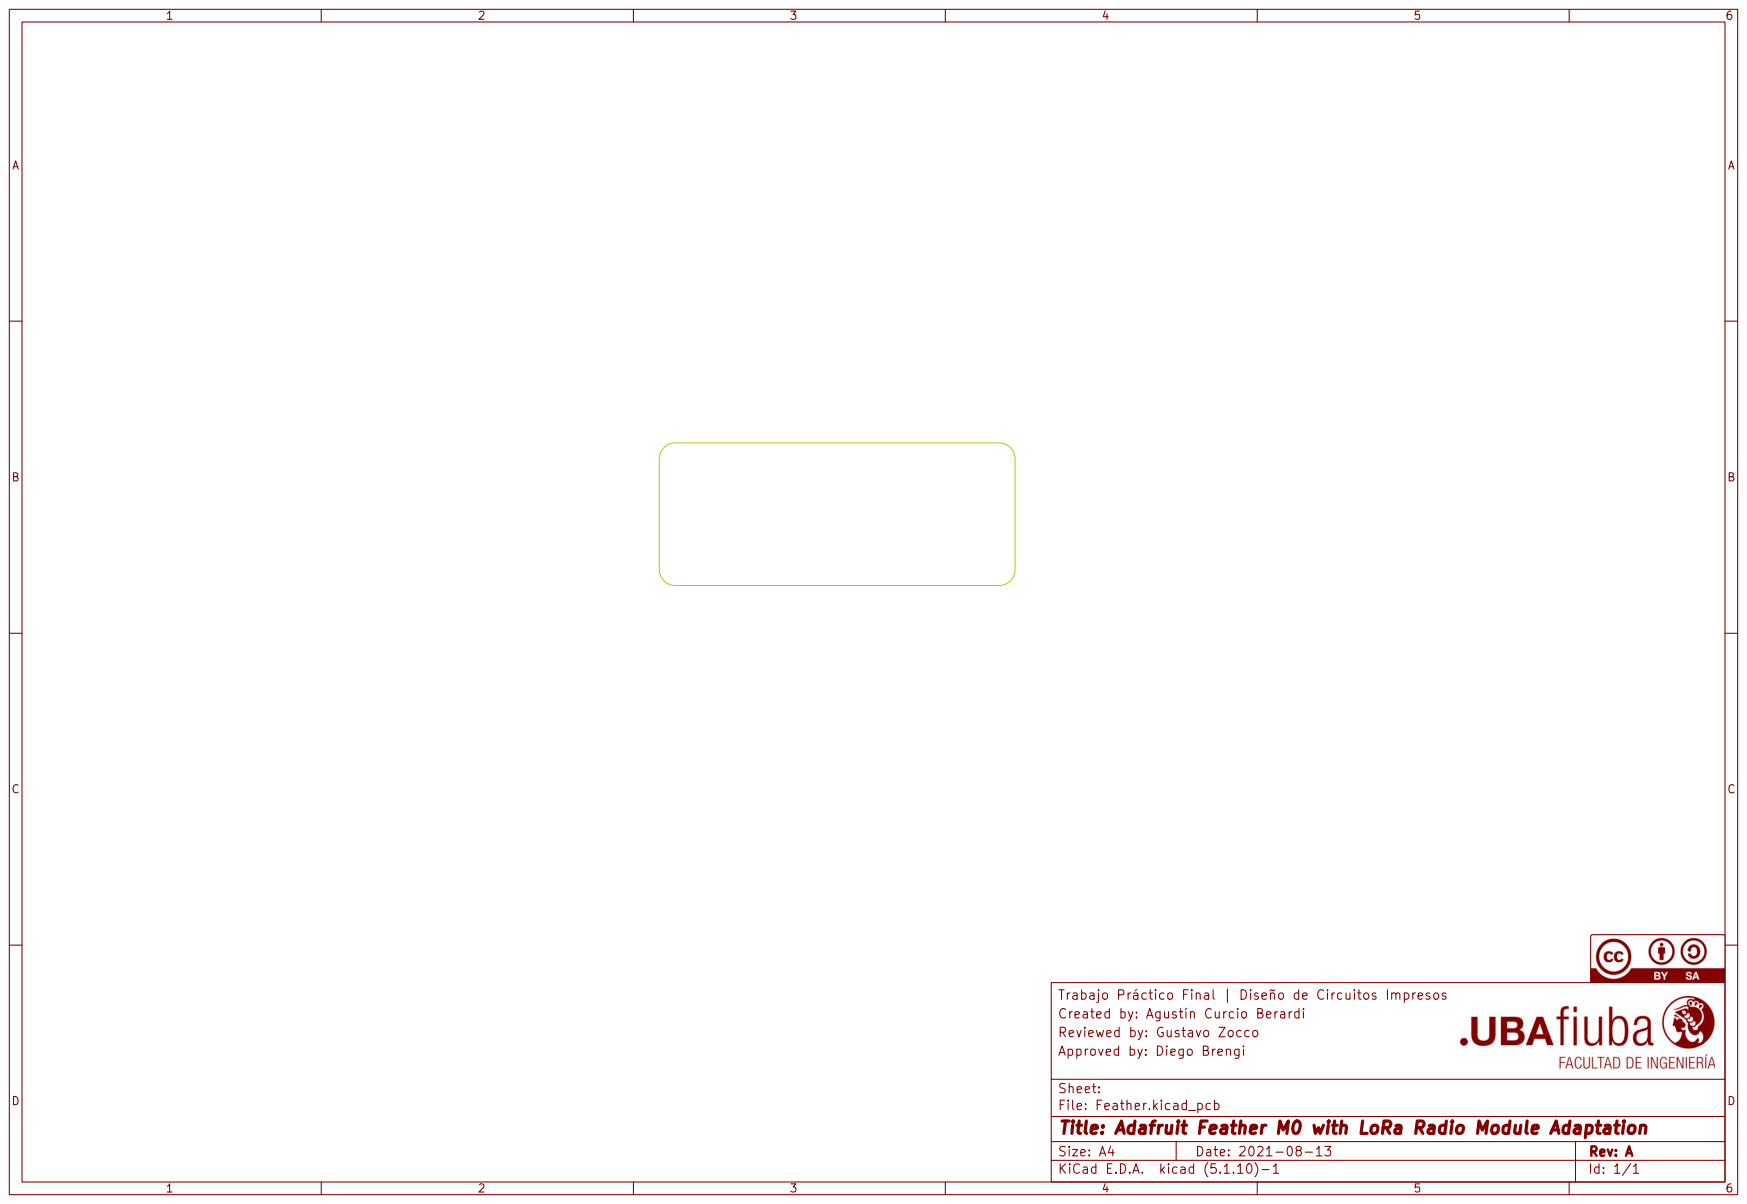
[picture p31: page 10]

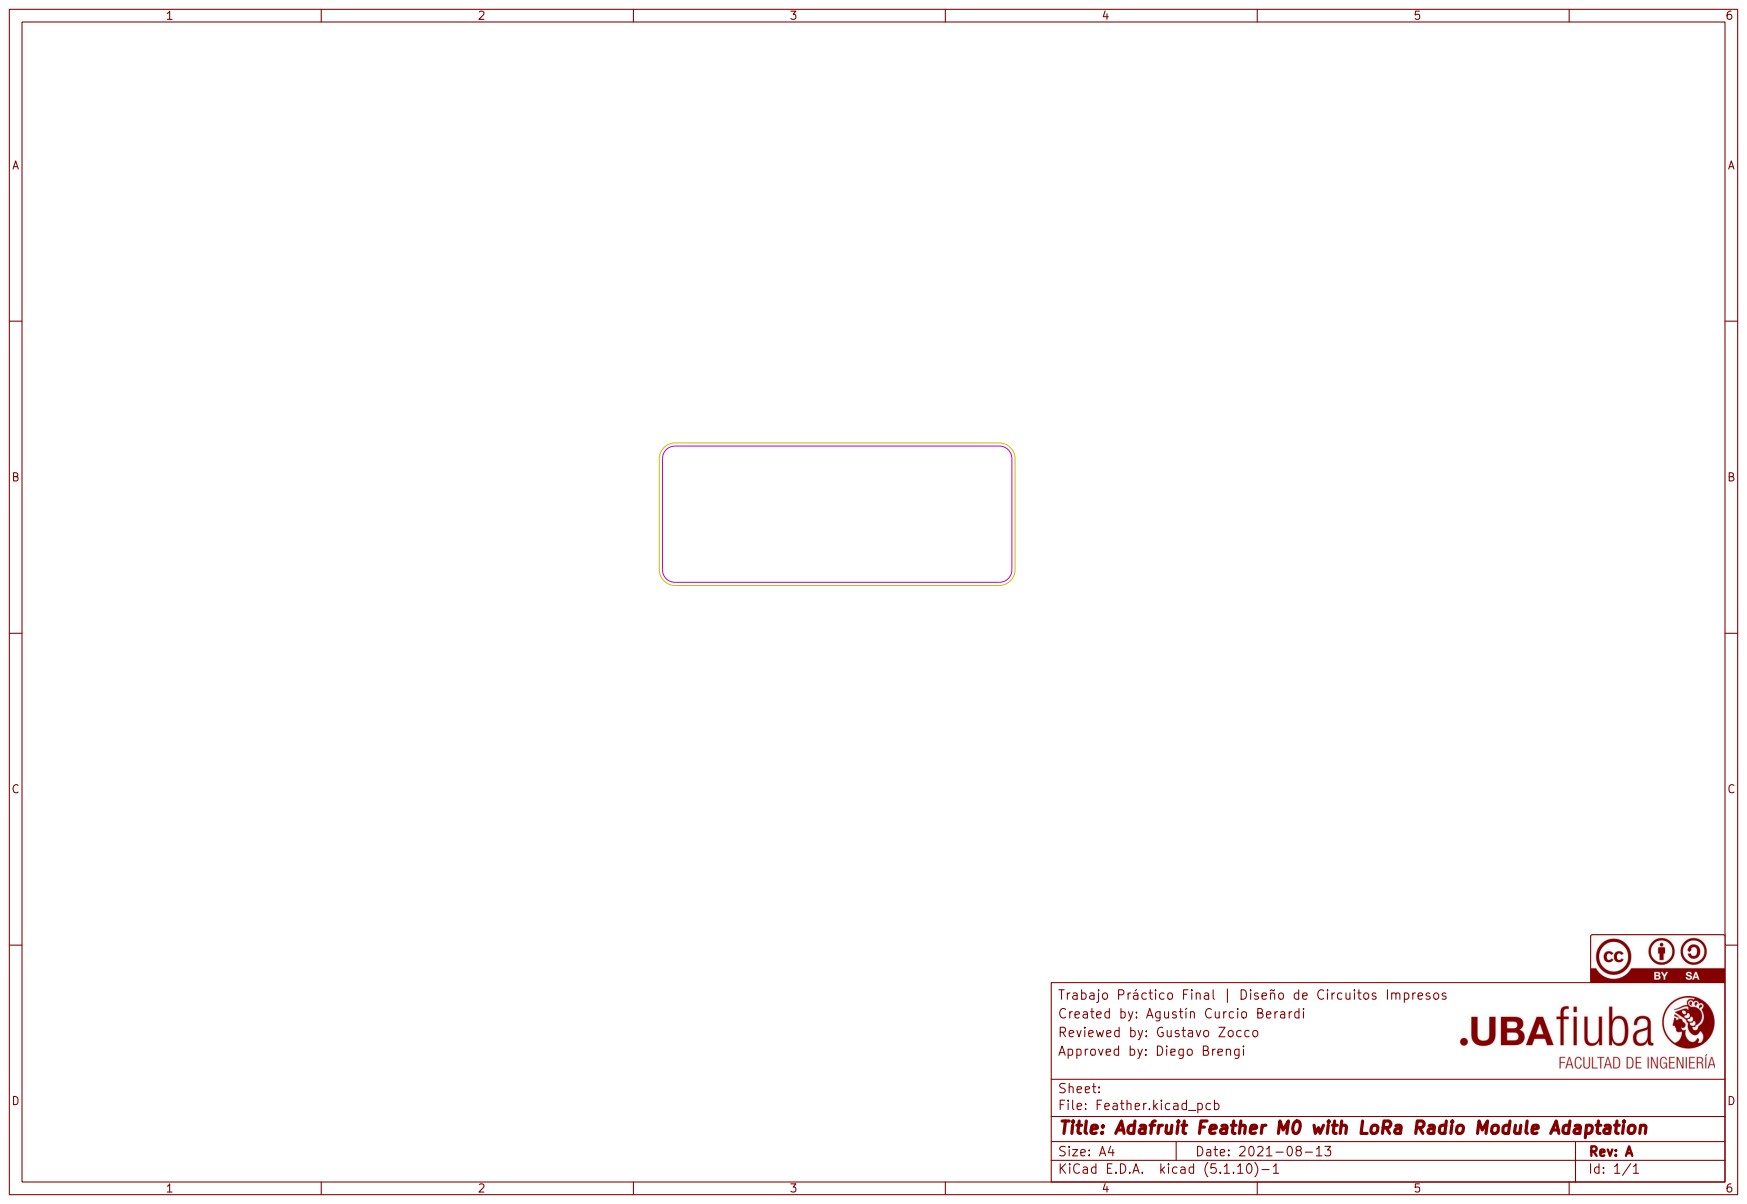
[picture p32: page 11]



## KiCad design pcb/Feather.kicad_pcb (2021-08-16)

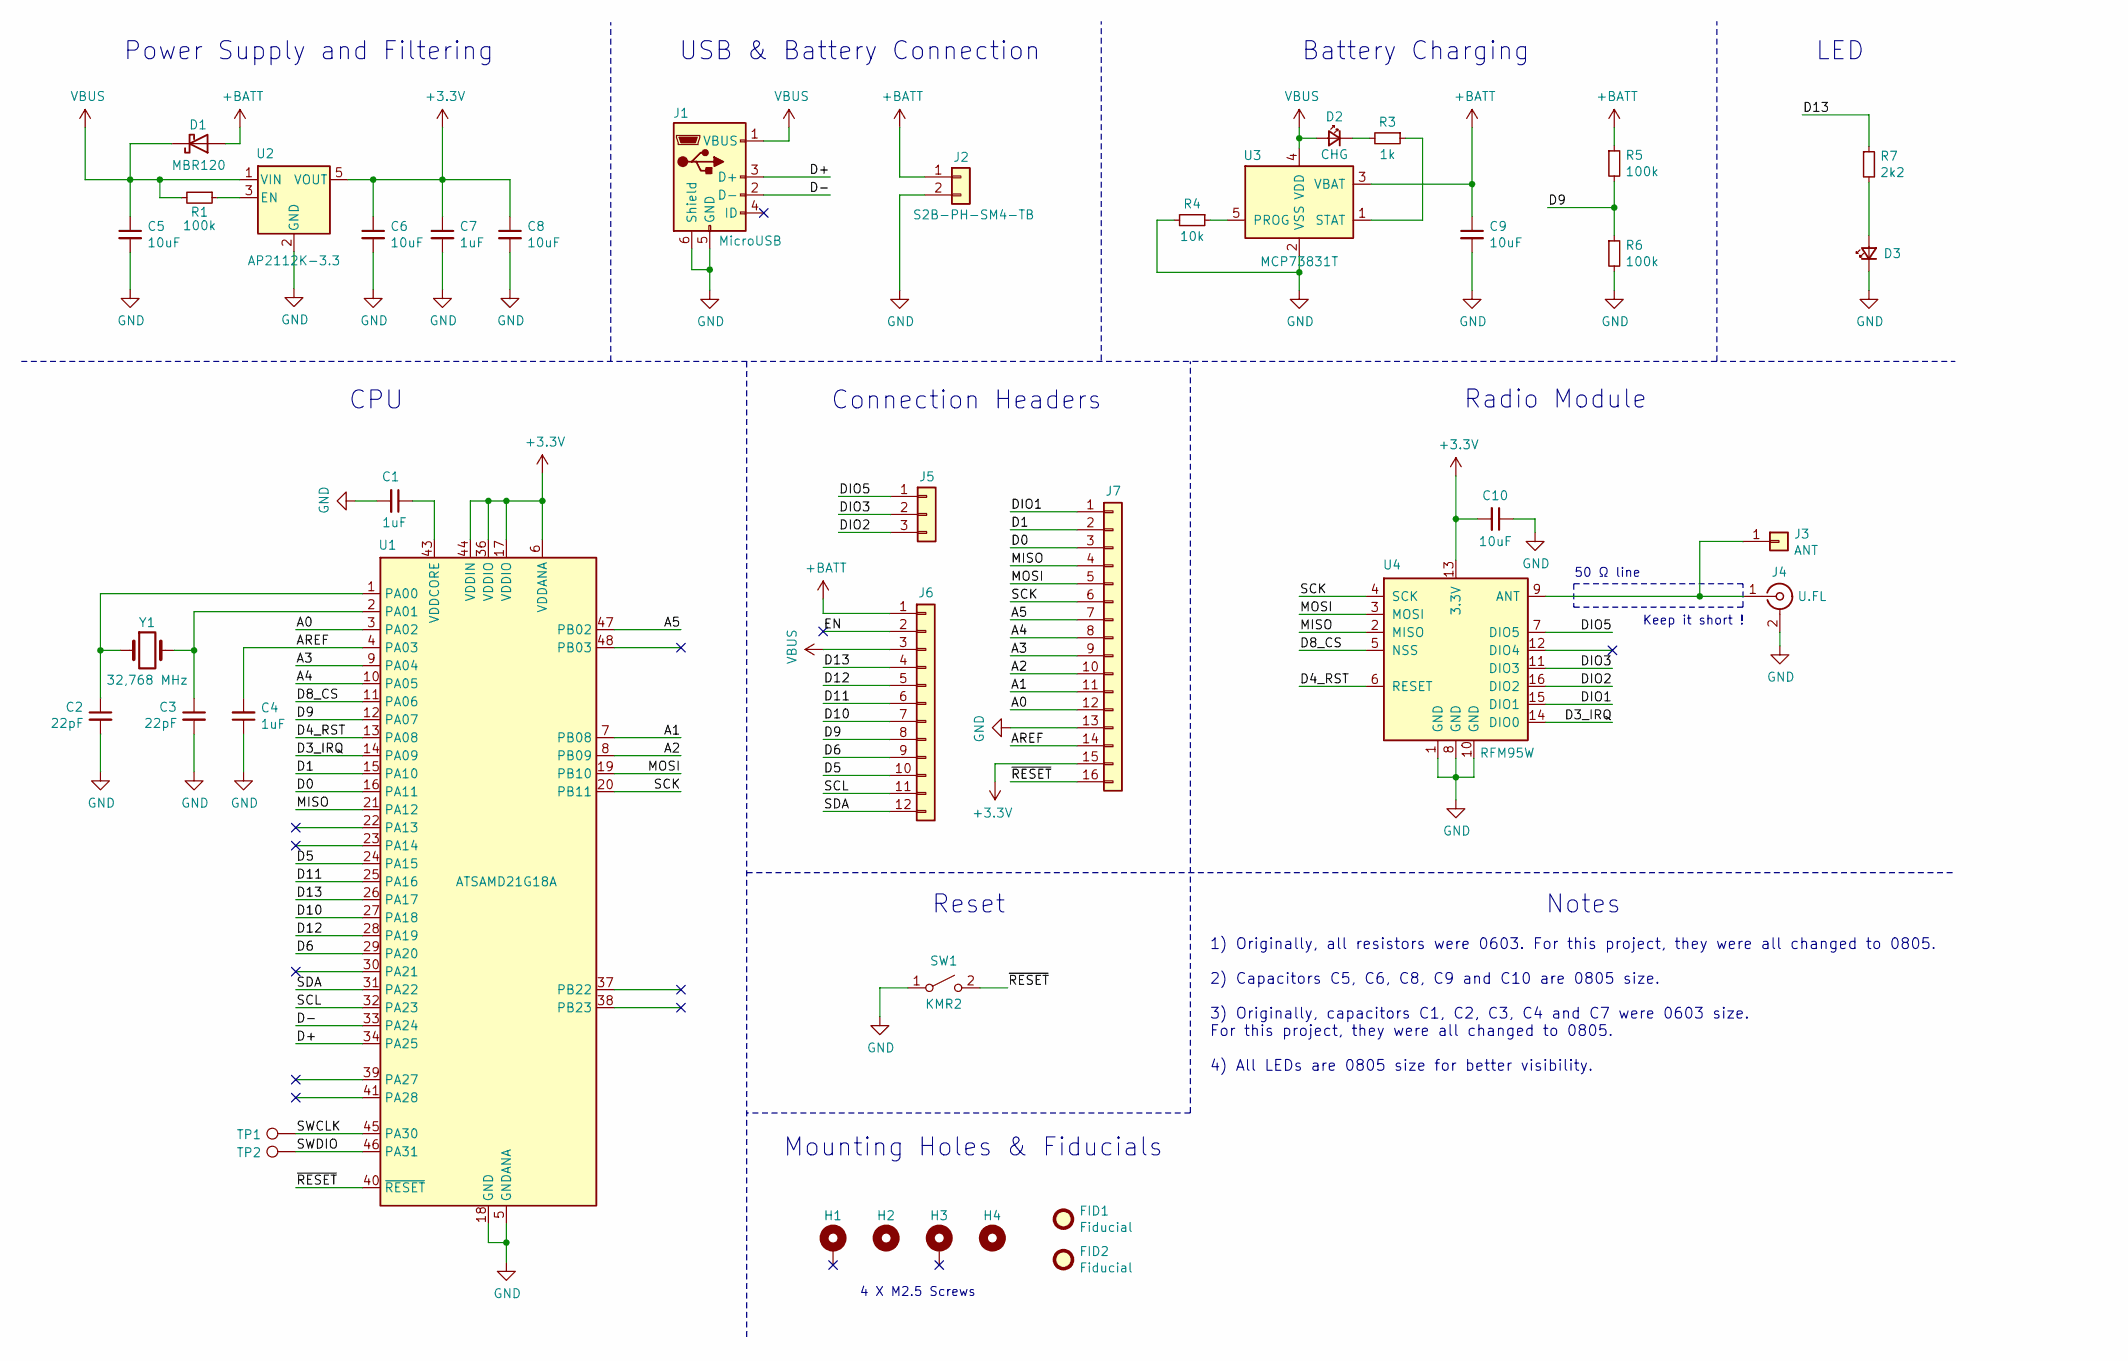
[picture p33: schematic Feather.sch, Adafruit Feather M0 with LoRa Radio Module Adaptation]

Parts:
C1, C4, C7: 1uF; C_0805_2012Metric
C2, C3: 22pF; C_0805_2012Metric
C5, C6, C8, C9, C10: 10uF; C_0805_2012Metric
D1: MBR120; D_SOD-123F
D2: CHG; LED_0805_2012Metric_Castellated
D3: PWR; LED_0805_2012Metric_Castellated
FID1, FID2: Fiducial; Fiducial_1mm_Mask2mm
H1, H3: Mounting Hole w/Pad; MountingHole_2.5mm_Pad_TopOnly
H2, H4: Mounting Hole; MountingHole_2.5mm
J1: MicroUSB; USB_Micro-B_Amphenol_10103594-0001LF_Horizontal
J2: S2B-PH-SM4-TB; JST_PH_S2B-PH-SM4-TB_1x02-1MP_P2.00mm_Horizontal
J3: ANT; Adafruit_Feather_PinHeader_1x01_P2.54mm
J4: U.FL; U.FL_Hirose_U.FL-R-SMT-1_Vertical
J5: Conn_01x03; Adafruit_Feather_PinHeader_1x03_P2.54mm
J6: Conn_01x12; Adafruit_Feather_PinHeader_1x12_P2.54mm
J7: Conn_01x16; Adafruit_Feather_PinHeader_1x16_P2.54mm
R1, R5, R6: 100k; R_0805_2012Metric
R3: 1k; R_0805_2012Metric
R4: 10k; R_0805_2012Metric
R7: 2k2; R_0805_2012Metric
SW1: KMR2; SW_Push_1P1T_NO_CK_KMR2
TP1, TP2: TestPoint; TestPoint_Pad_D1.5mm
U1: ATSAMD21G18A; QFN-48-1EP_7x7mm_P0.5mm_EP5.15x5.15mm
U2: AP2112K-3.3; SOT-23-5
U3: MCP73831T; SOT-23-5
U4: RFM95W; HOPERF_RFM9XW_SMD
Y1: 32,768 MHz; Crystal_SMD_3215-2Pin_3.2x1.5mm

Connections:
+3V3: C6.1, C7.1, C8.1, C10.2, J7.15, U1.6 (VDDANA), U1.17 (VDDIO), U1.36 (VDDIO), U1.44 (VDDIN), U2.5 (VOUT), U4.13 (3.3V)
+BATT: C9.1, D1.2 (A), J2.1, J6.1, R5.1, U3.3 (VBAT)
/A0: J7.12, U1.3 (PA02)
/A1: J7.11, U1.7 (PB08)
/A2: J7.10, U1.8 (PB09)
/A3: J7.9, U1.9 (PA04)
/A4: J7.8, U1.10 (PA05)
/A5: J7.7, U1.47 (PB02)
/AREF: C4.2, J7.14, U1.4 (PA03)
/D0: J7.3, U1.16 (PA11)
/D1: J7.2, U1.15 (PA10)
/D3_IRQ: U1.14 (PA09), U4.14 (DIO0)
/D4_RST: U1.13 (PA08), U4.6 (RESET)
/D5: J6.10, U1.24 (PA15)
/D6: J6.9, U1.29 (PA20)
/D8_CS: U1.11 (PA06), U4.5 (NSS)
/D9: J6.8, R5.2, R6.1, U1.12 (PA07)
/D10: J6.7, U1.27 (PA18)
/D11: J6.6, U1.25 (PA16)
/D12: J6.5, U1.28 (PA19)
/D13: J6.4, R7.1, U1.26 (PA17)
/D+: J1.3 (D+), U1.34 (PA25)
/D-: J1.2 (D-), U1.33 (PA24)
/DIO1: J7.1, U4.15 (DIO1)
/DIO2: J5.3, U4.16 (DIO2)
/DIO3: J5.2, U4.11 (DIO3)
/DIO5: J5.1, U4.7 (DIO5)
/EN: J6.2
/MISO: J7.4, U1.21 (PA12), U4.2 (MISO)
/MOSI: J7.5, U1.19 (PB10), U4.3 (MOSI)
/SCK: J7.6, U1.20 (PB11), U4.4 (SCK)
/SCL: J6.11, U1.32 (PA23)
/SDA: J6.12, U1.31 (PA22)
/SWCLK: TP1.1, U1.45 (PA30)
/SWDIO: TP2.1, U1.46 (PA31)
/~RESET: J7.16, SW1.2 (B), U1.40 (~RESET)
GND: C1.2, C2.2, C3.2, C4.1, C5.2, C6.2, C7.2, C8.2, C9.2, C10.1, D3.1 (K), J1.5 (GND), J1.6 (Shield), J2.2, J4.2 (Ext), J7.13, R4.2, R6.2, SW1.1 (A), U1.5 (GNDANA), U1.18 (GND), U1.35 (GND), U1.42 (GND), U1.49 (EP), U2.2 (GND), U3.2 (VSS), U4.1 (GND), U4.8 (GND), U4.10 (GND)
unnamed: C1.1, U1.43 (VDDCORE)
unnamed: C2.1, U1.1 (PA00), Y1.1
unnamed: C3.1, U1.2 (PA01), Y1.2
unnamed: D2.1 (K), R3.2
unnamed: D3.2 (A), R7.2
unnamed: J3.1, J4.1 (In), U4.9 (ANT)
unnamed: R1.1, U2.3 (EN)
unnamed: R3.1, U3.1 (STAT)
unnamed: R4.1, U3.5 (PROG)
VBUS: C5.1, D1.1 (K), D2.2 (A), J1.1 (VBUS), J6.3, R1.2, U2.1 (VIN), U3.4 (VDD)

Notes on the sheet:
USB & Battery Connection
Battery Charging
LED
CPU
Connection Headers
Radio Module
1) Originally, all resistors were 0603. For this project, they were all changed to 0805. 2) Capacitors C5, C6, C8, C9 and C10 are 0805 size. 3) Originally, capacitors C1, C2, C3, C4 and C7 were 0603 size. For this project, they were all changed to 0805. 4) All LEDs are 0805 size for better visibili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
Notes
Keep it short !
50 Ω line
Power Supply and Filtering
Reset
Mounting Holes & Fiducials
4 X M2.5 Screws

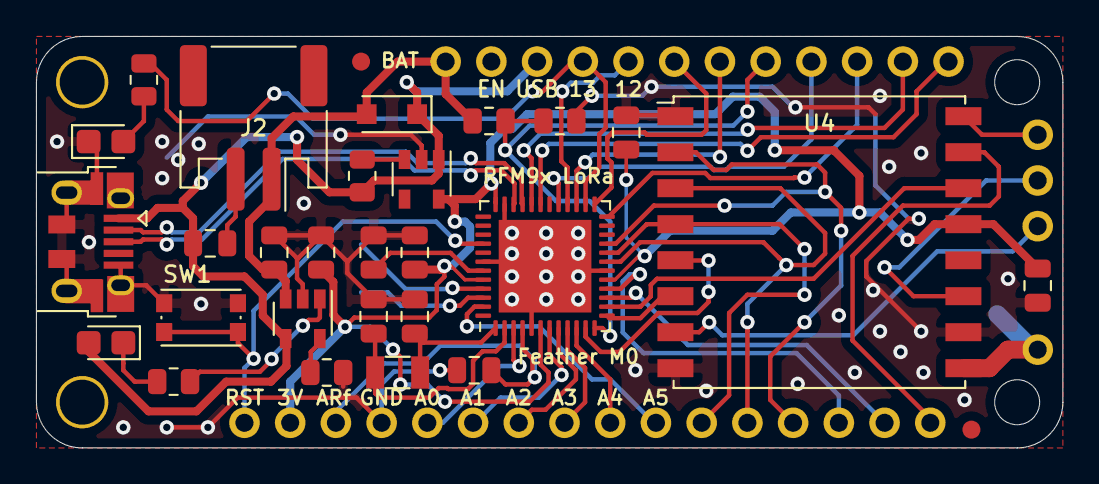
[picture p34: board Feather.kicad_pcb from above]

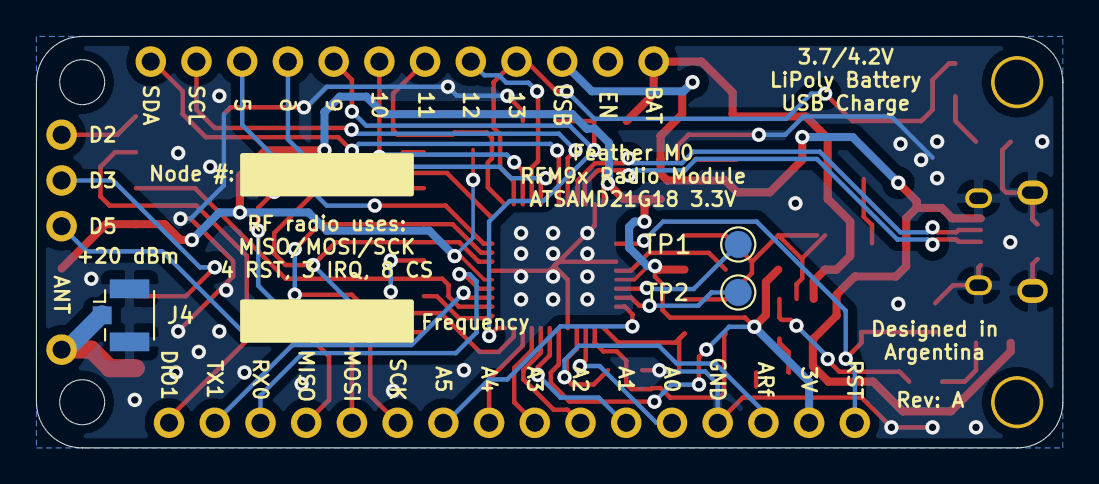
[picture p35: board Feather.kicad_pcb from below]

Board: 2 copper layers, 57.0 x 22.9 mm, 40 parts (3 on the bottom side), 46 nets.

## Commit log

2021-06-26 En este commit inicial se agrega el esquemático completo de la placa Adafruit Feather M0 junto con las hojas de datos de sus principales componentes.
    [Feather.kicad_pcb, Feather.sch]
2021-06-27 Se agregan los modelos 3D que estaban faltando así como también la documentación y hojas de datos faltantes.
    [Abracon_ABS07AIG.step, Amphenol_10118192C.step, C&K_KMR2_Switch.step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]
2021-06-27 Se crea la biblioteca Adafruit_PinHeader para las tiras de pines que se deben soldar en los costados de la placa. Con esta modificación, se actualizo también el circuito esquemático. Listo para corre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
    [Feather.sch]
2021-06-28 Se realizan leves ajustes en el esquemático y se adiciona el archivo de licencia. Listo para revisar.
    [Feather.sch]
2021-06-28 Se agrega el esquemático en formato PDF para facilitar su revisión.
    [Feather.sch]
2021-07-30 Se modifica todo el proyecto para utilizar componentes 0805 en lugar de 0603 que se usan en el circuito original. Se incorpora archivo del PCB, con componentes posicionados y con modelos 3D incluídos.
    [Feather.sch, Hoperf_RFM_95_96_97_98_1.step]
2021-08-09 Se hicieron más ajustes para acomodar mejor los componentes tamaño 0805 no contemplados al comienzo del posicionamiento.
    [Feather.kicad_pcb]
2021-08-09 Se agrega margen en el circuito a 0,5 mm del borde de placa.
    [Feather.kicad_pcb]
2021-08-11 Se corrigen las observaciones realizadas por el docente. Adicionalmente se sube el ruteo de la placa.
    [Feather.kicad_pcb, Feather.sch]
2021-08-11 Se modifica la CPW de la línea de antena y se agrega el cálculo.
    [Feather.kicad_pcb]
2021-08-16 Últimos retoques en el PCB de acuerdo a las correcciones realizadas.
    [Feather.kicad_pcb, Feather.sch]
2021-08-16 Se agrega el README de la propuesta.
2021-08-16 Se modifica el README principal del Trabajo.
2021-08-16 Se agregó un README con los cálculos de líneas de transmisión.
2021-08-16 Se agregaron cálculos de líneas con impedancia controlada.
2021-08-16 Se agrega detalle de adaptaciones realizadas en el archivo README.md principal.
2021-08-16 Se modifica el tamaño de la fotografía de vista superior para que sea igual a la del lado inferior.
2021-08-16 Modificación de imagen superior.
2021-08-16 Se actualizan los archivos PDF del esquemático y circuito impreso.
2021-08-16 Se elimina README de la sección PCB.
2021-08-16 Leves ajustes en el texto aclaratorio del PCB.
    [Feather.kicad_pcb]
2021-08-16 Se agregaron algunas regiones de 'keep out' en el cobre superior para mejorar la prolijidad del circuito.
    [Feather.kicad_pcb]
2021-08-16 Se realizaron ajustes a los 'keep outs' de la capa de cobre superior.
    [Feather.kicad_pcb]
2021-08-17 Se agregaron todos los componentes 3D de las bibliotecas de KiCAD al proyecto.
